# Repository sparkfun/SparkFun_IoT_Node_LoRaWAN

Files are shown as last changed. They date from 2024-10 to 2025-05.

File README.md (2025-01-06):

SparkFun IoT Node - LoRaWAN
========================================

SparkFun IoT Node - LoRaWAN (https://www.sparkfun.com/products/26060)

[*SparkFun IoT Node - LoRaWAN (WRL-26060)*](https://www.sparkfun.com/products/26060)




The SparkFun IoT Node – LoRaWAN development board brings an entirely new level of usability to the often convoluted and configuration-intensive effort to set up a LoRaWAN™-based IoT Device. Combining the ease of LoRaWAN™ setup and configuration delivered by the Digi X-ON™ system with the rapid prototyping provided by the SparkFun Qwiic ecosystem, the SparkFun IoT Node – LoRaWAN development board accelerates IoT end-node creation and deployment.  

**Out of the Box**

With the integration of Digi X-ON™ technology, the SparkFun IoT Node – LoRaWAN board allows the creation and deployment of a LoRaWAN™ IoT sensor in minutes. 

* Set up the Digi HX15 Gateway for LoRaWAN and corresponding Digi account.  
* Register the IoT Node – LoRaWAN board quickly using the digital data block on the module.
* Add the antenna and a supported Qwiic sensor to the Node board 
* Power the board  

The SparkFun IoT Node – LoRaWAN board is shipped with firmware installed that Digi HX15 Gateway for LoRaWAN automatically connects to Digi X-ON, detects an attached sensor, and posts data to the X-ON cloud. Configured via a serial console connection, this application allows rapid evaluation and creation of a LoRaWAN™ IoT device.  

The pre-installed application is also open source and readily available, enabling rapid customization if desired.

**Firmware Development**

The firmware development for the SparkFun IoT Node – LoRaWAN board is performed primarily in the Arduino environment and enabled by an Arduino XBee® LR library from Digi. Combining the easy LoRaWAN™ access provided by the Digi library with the wide range of Qwiic sensors available from SparkFun, the possibilities of potential LoRaWAN™ IoT sensors are endless. 

Additionally, the pre-installed application is open source and readily available, enabling rapid customization if desired.  

**Hardware**

At the heart of the IoT Node – LoRaWAN board is the RP2350 microprocessor from Raspberry Pi, supporting many development environments, including Arduino, micropython, and the Raspberry Pi pico SDK. Besides the capabilities the RP2350 provides, we’ve kitted out the processer with all the goodies your project might require: 

* 16 MB of flash 
* 8 MB PSRAM 
* Qwiic connector 
* On-board Lithium Ion (LiPo) battery charging 
* Fuel gauge circuits 
* microSD card  
* A variety of IO pins 
* RGB LED and user button 

The Digi XBee® LR module for LoRaWAN module is directly connected to a serial port of the RP2350, allowing direct control and access to the LoRaWAN™ module via a development library provided by Digi.  

The XBee® LR for LoRaWAN™ module is the latest LoRaWAN™ module from Digi, delivering unmatched operational performance and onboarding simplicity. The Digi XBee® LR uses LoRa™ modulation for Non-Line-of-Sight (NLOS) two-way communications for long-range and high-noise RF environments. Since each module is pre-activated on Digi's X-ON™ cloud platform, automated connection and two-way device management are a breeze.

Repository Contents
-------------------

* **/Hardware** - KiCAD design files (.brd, .sch)
* **/Documents** - Files related to the hardware on the board
* **/docs** - Hookup guide files

Documentation
--------------
* **[Hookup Guide](https://docs.sparkfun.com/SparkFun_IoT_Node_LoRaWAN)** - Basic hookup guide for the SparkFun IoT Node for LoRaWAN®.
* **[Firmware Guide](https://docs.sparkfun.com/sfe-iot-node-lorawan/)** - Firmware guide for the SparkFun IoT Node for LoRaWAN®.

License Information
-------------------

This product is _**open source**_! 

Please review the LICENSE.md file for license information. 

If you have any questions or concerns on licensing, please contact technical support on our [SparkFun forums](https://forum.sparkfun.com/viewforum.php?f=152).

Distributed as-is; no warranty is given.

- Your friends at SparkFun.

_<COLLABORATION CREDIT>_

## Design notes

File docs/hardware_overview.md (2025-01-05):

---
icon: material/cog
---

## XBee LR LoRaWAN® Module

The XBee® LR from Digi is a wireless communications module that supports the LoRaWAN® communications protocol, enabling direct communication with standards-compliant LoRaWAN® gateways and Network Server cloud software over long range with very low-power consumption. It comes pre-activated with Digi X-ON™ - a complete device-to-cloud platform for connected IoT devices which provides a simplified Digi Embedded API and AT command interpreter to interface with your sensor over serial. Scanning the QR Code on the module will take you directly to the Digi X-ON cloud platform for automated connection and two-way device management. For more information, refer to the [datasheet](assets/component_documentation/Digi-XBLR-Datasheet.pdf).

<!--ISM 902 to 928 MHz, 868 to 870 MHz
LoRaWAN® 1.0.4, OTAA, ABP
-->

<figure markdown>
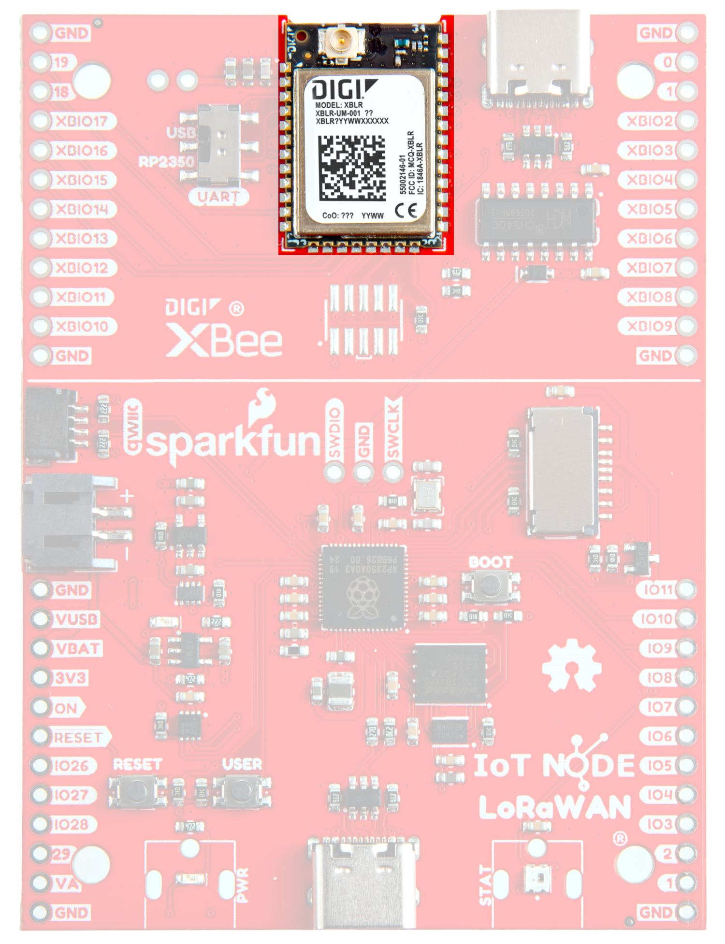
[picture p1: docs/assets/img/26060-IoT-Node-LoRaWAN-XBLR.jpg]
XBee LR LoRaWAN Module

<figcaption markdown>XBee LR LoRaWAN® Module</figcaption>
</figure>

## RP2350

The RP2350 is part of a new family of microcontrollers from Raspberry Pi that offers significant enhancements over RP2040. Along with the Dual ARM M33/RISC-V Hazard 3 CPU core running at a frequency of 150MHz and double the amount of internal RAM, the RP2350 also includes 8MB of PSRAM as well as a host of peripherals. As shipped, the SparkFun IoT Node for LoRaWAN® board makes use of the ARM M33 Core, but the user has the option to change to the RISC-V Hazard 3 CPU Core. More information can be found in the datasheet [here](assets/component_documentation/).

<figure markdown>
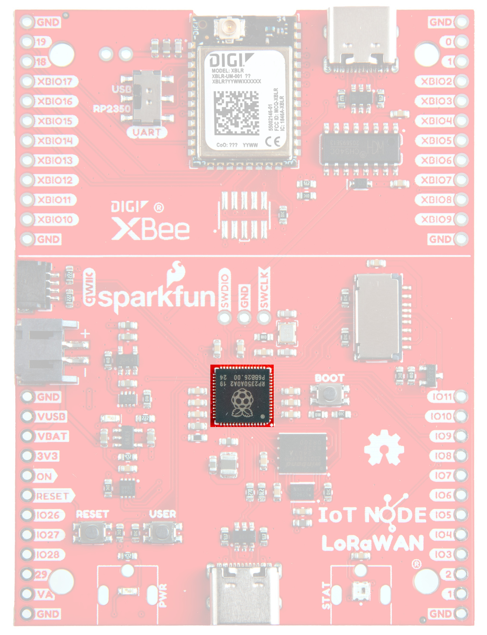
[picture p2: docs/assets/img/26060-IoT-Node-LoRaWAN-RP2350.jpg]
RP2350

<figcaption markdown>RP2350</figcaption>
</figure>

## Power & Voltage Regulation

While max input power is 5.5V for the board, the LM66200 regulates the voltage down to 3.3 for the majority of the components on the board. 

<figure markdown>
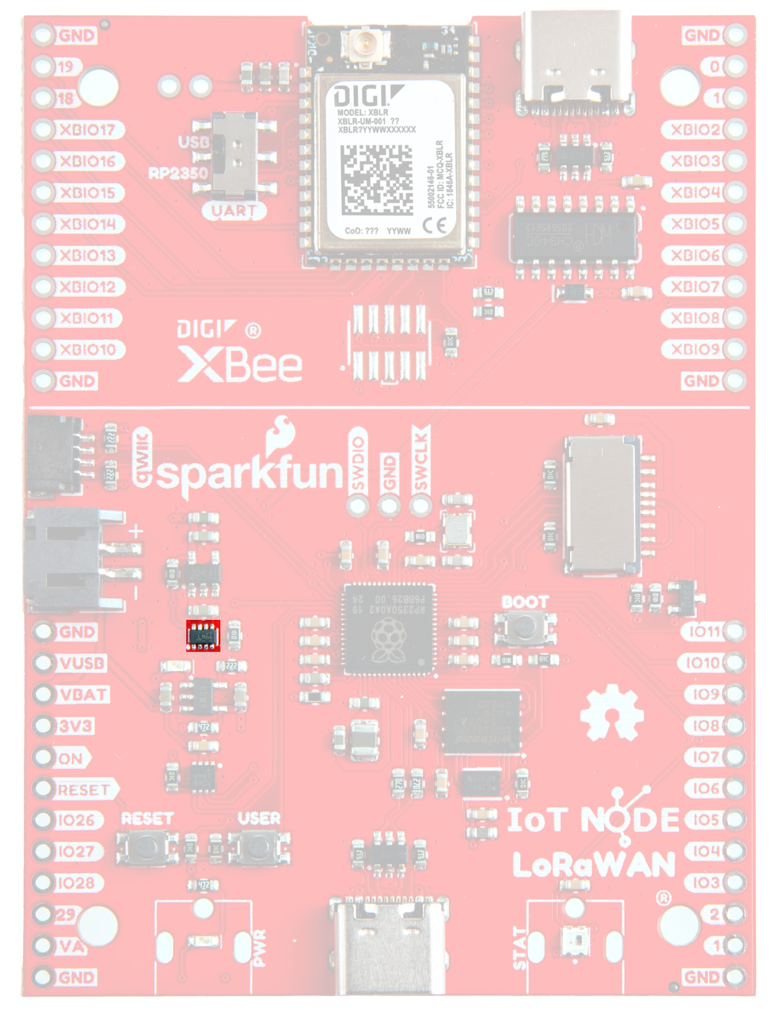
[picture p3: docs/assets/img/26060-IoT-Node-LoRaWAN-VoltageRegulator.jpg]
LM66200

<figcaption markdown>LM66200</figcaption>
</figure>

## Qwiic connector

The Qwiic connector on the side of the board provides power and I<sup>2</sup>C connectivity simultaneously to our rich array of Qwiic sensors. More information on our Qwiic Ecosystem [can be found here](https://www.sparkfun.com/qwiic). 

<figure markdown>
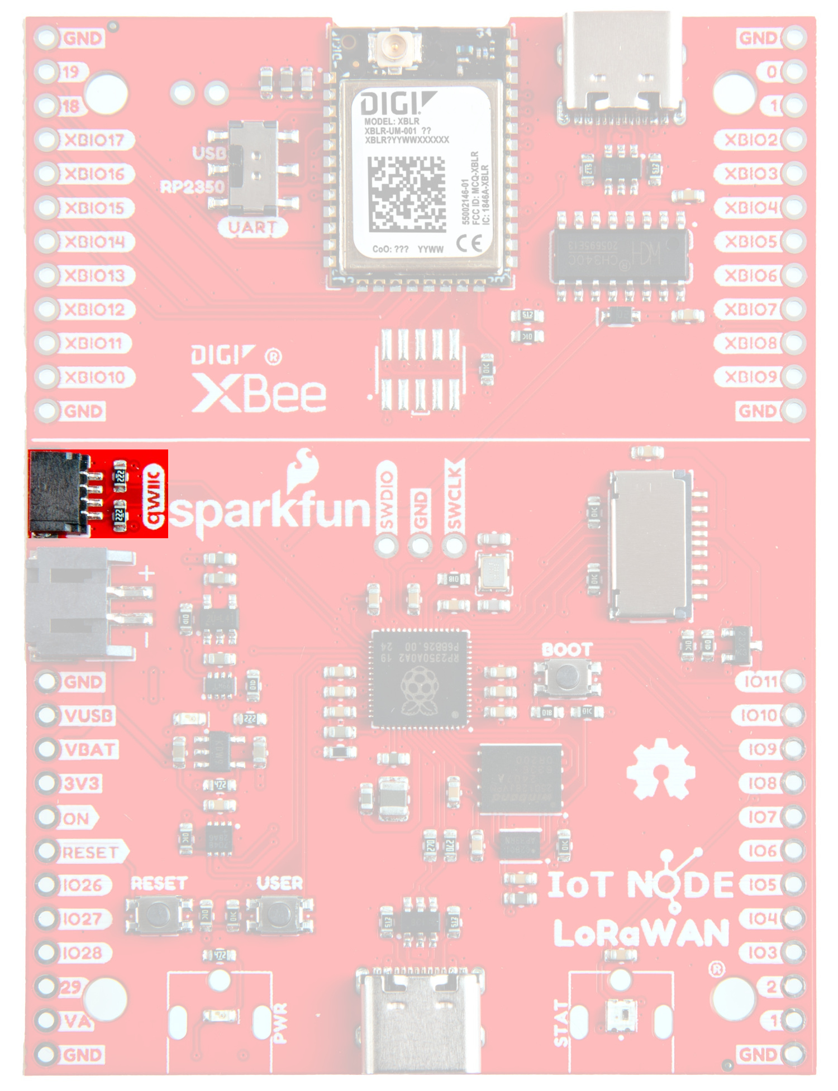
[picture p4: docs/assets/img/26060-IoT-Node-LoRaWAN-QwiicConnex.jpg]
Qwiic connector

<figcaption markdown>Qwiic connector</figcaption>
</figure>

## XBLR UART Selection Switch

This selection switch allows you to choose whether you talk to the XBee LR via the Raspberry Pi or the USB connector at the top of the board. Unless there is a need to talk to the XBee directly (ie, debugging, etc), it is recommended to leave the switch on the RP2350.

<figure markdown>
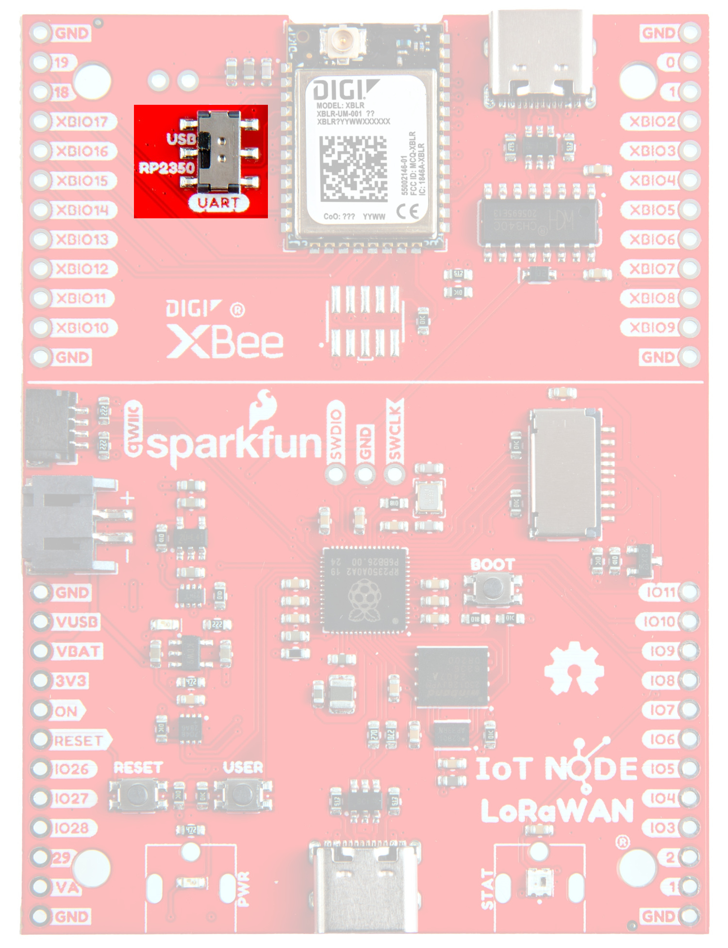
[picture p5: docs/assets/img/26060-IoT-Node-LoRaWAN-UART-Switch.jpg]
XBLR UART Selection Switch

<figcaption markdown>UART Selection Switch</figcaption>
</figure>

## RP2350 Debug Header

Should you need breakpoint level debugging, we've broken out a debug header for the RP2350. Standard pinout for the ARM Cortex. 

<figure markdown>
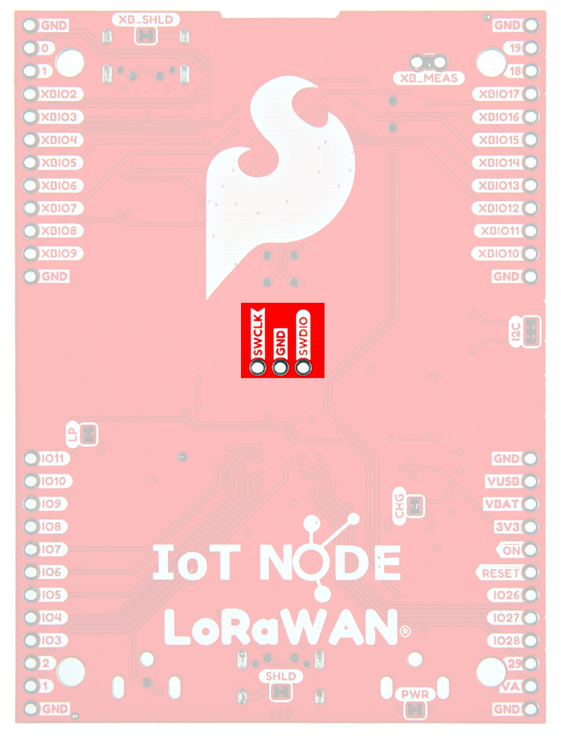
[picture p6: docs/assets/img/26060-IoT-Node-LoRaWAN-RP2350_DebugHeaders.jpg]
RP2350 Debug Headers

<figcaption markdown>RP2350 Debug Header</figcaption>
</figure>

## XBee LR Debug Header

Similar to the debug header for the RP2350, these pads allow for breakpoint level debugging of the XBee module. Unlike the RP2350 Debug Header, however, these pads are unpopulated. 

<figure markdown>
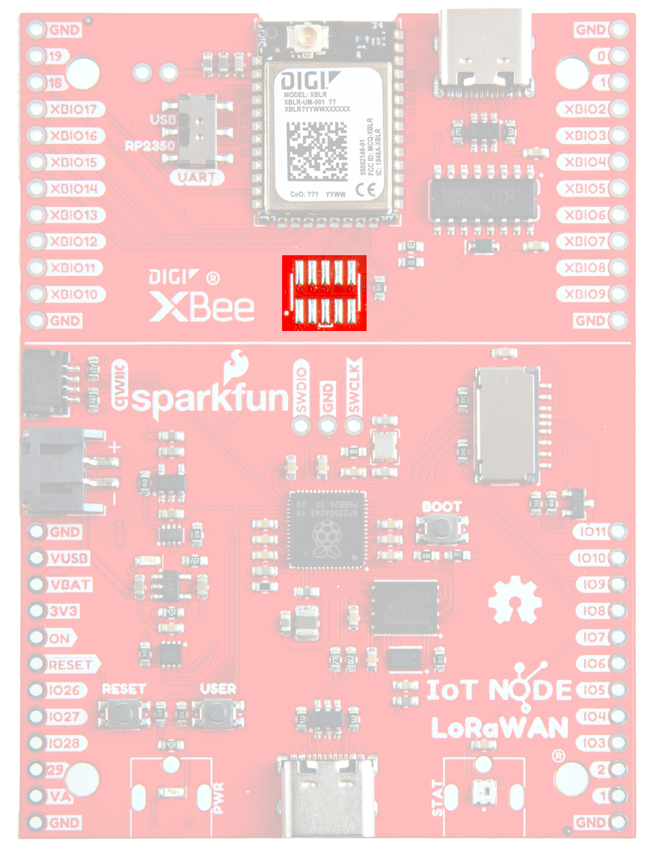
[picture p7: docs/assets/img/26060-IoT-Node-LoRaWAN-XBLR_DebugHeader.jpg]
XBee LR Debug Header

<figcaption markdown>XBee LR Debug Header</figcaption>
</figure>

## MicroSD Card

The microSD card slot allows for data logging or for more advanced users, easy upload of firmware programming files for the Raspberry Pi.

!!! warning
	Do NOT drive the microSD card pins high if the card is not powered. Damage could occur! 

<figure markdown>
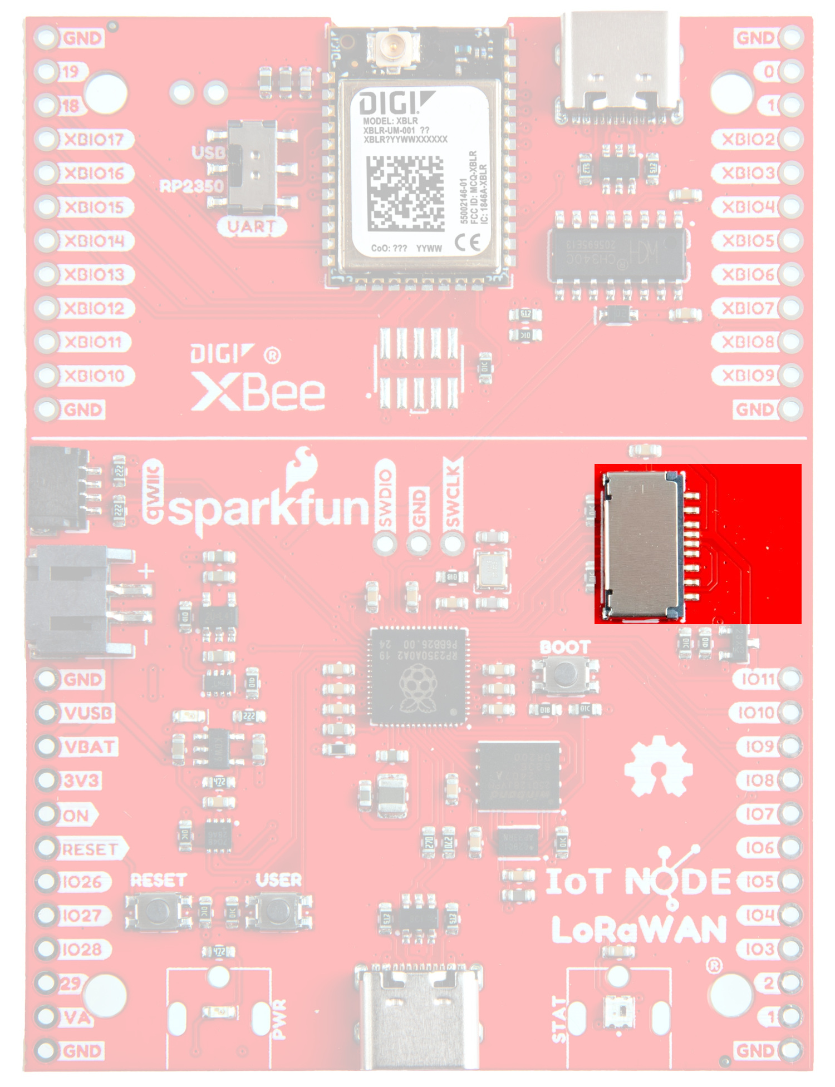
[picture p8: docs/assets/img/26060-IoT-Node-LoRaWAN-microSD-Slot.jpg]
microSD card slot

<figcaption markdown>microSD Card Slot</figcaption>
</figure>

## Battery Charging Circuit

The MCP73831 has been integrated to allow for charging of a LiPo Battery via the JST connector. 

<figure markdown>
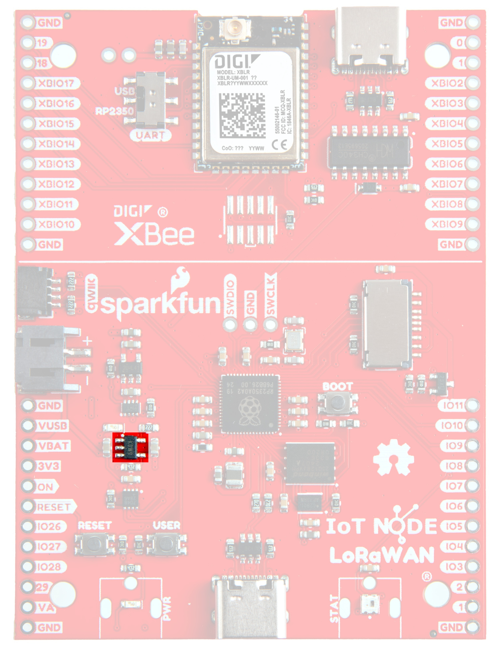
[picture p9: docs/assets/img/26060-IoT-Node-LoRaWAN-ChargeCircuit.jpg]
Battery Charging Circuit

<figcaption markdown>MCP73831</figcaption>
</figure>

Charging occurs at a rate of 455mA. Our calculation of this rate is via the equation below: 

<figure markdown>
Charge Circuit Equation
<figcaption markdown>Charge Circuit Equation</figcaption>
</figure>

## Buttons

<figure markdown>
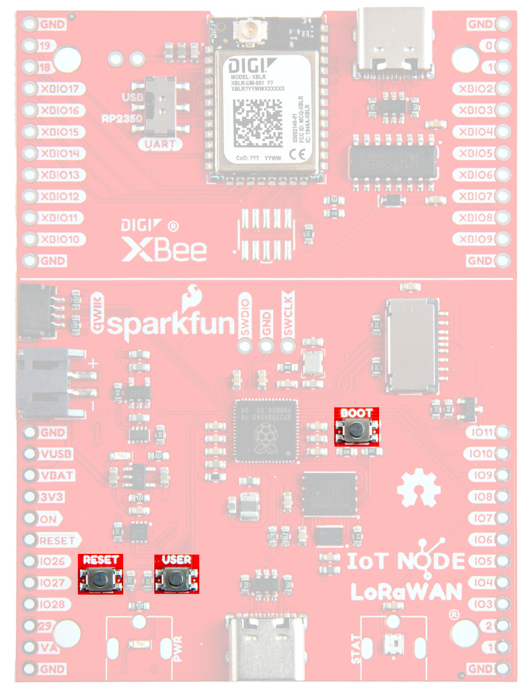
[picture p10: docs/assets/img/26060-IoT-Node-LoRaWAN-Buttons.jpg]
Boot, Reset, and User Buttons

<figcaption markdown>Boot, Reset, and User Buttons</figcaption>
</figure>

* <b>Boot:</b>
	Pressing and holding the boot button will set the board into boot select mode. This sets up as a mass storage device, which allows for drag-and-drop functionality for uploading uf2 programming files. For more information about the UF2 Bootloader, refer to the [Software/Bootloader](./uf2.md) section of this tutorial. 
* <b>Reset:</b>
	The reset button does a software reset on the RP2350. 
* <b>User Button:</b>
	The User Button is a user-defined general use button connected to GPIO. 

## Jumpers

??? note "Never modified a jumper before?"
	Check out our <a href="https://learn.sparkfun.com/tutorials/664">Jumper Pads and PCB Traces tutorial</a> for a quick introduction!
	<p align="center">
		<a href="https://learn.sparkfun.com/tutorials/664">
		Tutorial's thumbnail<br>
        How to Work with Jumper Pads and PCB Traces</a>
	</p>

<figure markdown>
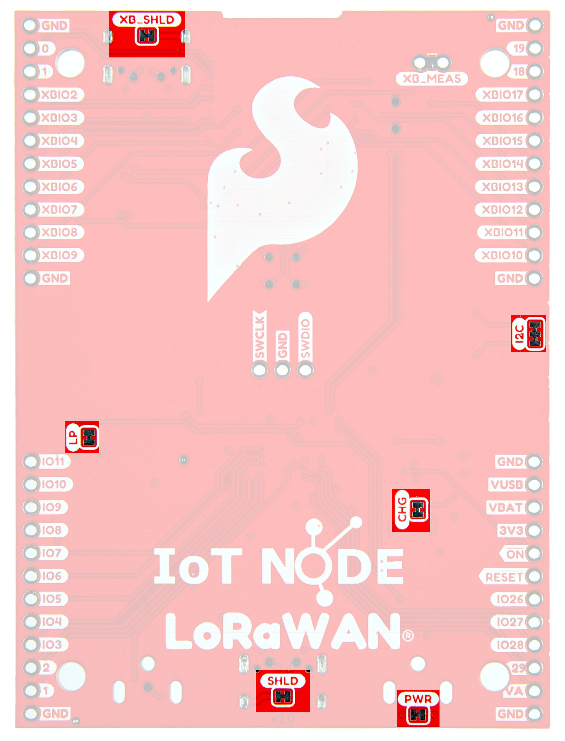
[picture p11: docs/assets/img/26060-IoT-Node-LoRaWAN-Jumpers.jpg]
Jumpers

<figcaption markdown>Jumpers</figcaption>
</figure>

* <b>XB_SHLD: </b>
	For most applications, single point grounding is sufficient. However, should you run into problems with EMI/EMC, we've provided a jumper that allow you to disconnect the XBee connector from ground.
* <b>XB_MEAS: </b>
	Cut this trace to measure the current consumed by the XBee LR. 
* <b>LP:</b>
	Cut the LP trace to make the microSD card and the RGB LED powered off by default. This functionality can then be controlled by GPIO. 
* <b>CHG:</b>
	Cut the CHG trace to disable the CHG LED. 
* <b>SHLD:</b>
	Should you run into problems with EMI/EMC, we've provided a jumper that allow you to disconnect the USB Shield from ground.
* <b>PWR:</b>
	Cut the PWR trace to disable the Power LED. 
* <b>I<sup>2</sup>C:</b>
	The SparkFun IoT Node for LoRaWAN® board has built-in 2.2k pull-up resistors on the SDA and SCL lines. These are needed for normal I<sup>2</sup>C communication. The I<sup>2</sup>C jumper has two small traces connecting the pull-ups to 3.3V. **For general use you can leave this jumper unmodified.** If you have many (over 7) devices on the I<sup>2</sup>C bus, each with their own pull up resistors, then you may want to [cut the I<sup>2</sup>C jumpers](https://learn.sparkfun.com/tutorials/how-to-work-with-jumper-pads-and-pcb-traces) to disconnect the 2.2k resistors on each Qwiic board.

## Board Dimensions

The board dimensions are illustrated in the drawing below; the listed measurements are in millimeters.

<figure markdown>
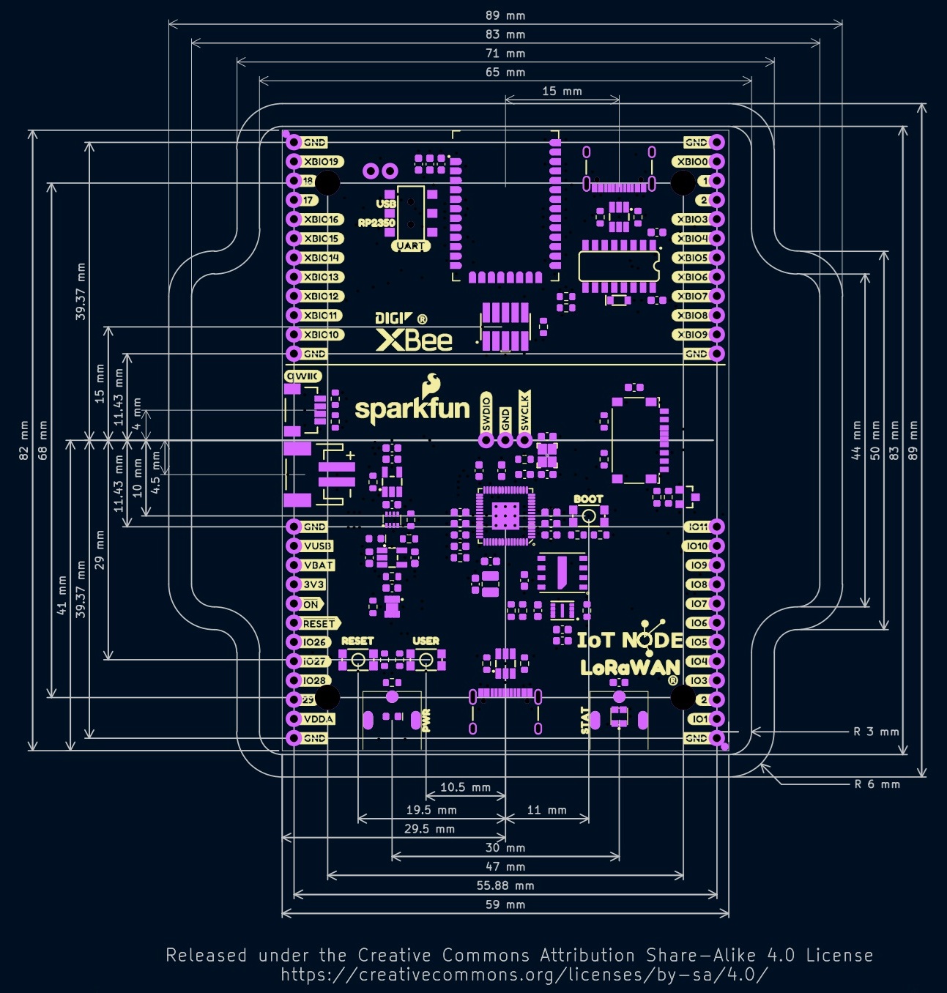
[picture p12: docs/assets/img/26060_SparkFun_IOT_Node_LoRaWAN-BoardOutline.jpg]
Board measures 59mm x 82mm

<figcaption markdown>SparkFun IoT Node for LoRaWAN® Board Dimensions</figcaption>
</figure>

??? tip "Need more measurements?"
	For more information about the board's dimensions, users can download the [KiCad files](../assets/board_files/SparkFun_IoT_Node_LoRaWAN_KiCADFiles.zip) for the board. These files can be opened in KiCad and additional measurements can be made with the dimensions tool.

	??? info ":octicons-download-16:{ .heart } Eagle - Free Download!"
		KiCAD is a [CAD]("computer-aided design") program for electronics that is free to use for hobbyists and students. However, it does require an account registration to utilize the software.

		<center>
		[Download from<br>:autodesk-primary:{ .autodesk }](https://www.kicad.org/download/ "Go to downloads page"){ .md-button .md-button--primary width="250px" }
		</center>

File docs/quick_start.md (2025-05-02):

---
icon: material/run-fast
hide: toc
---

<div class="grid cards desc" markdown>

-    <a href="https://www.sparkfun.com/products/26060">
    **SparkFun IoT Node for LoRaWAN®**<br>
    **SKU:** WRL-26060

    ---

    <figure markdown>
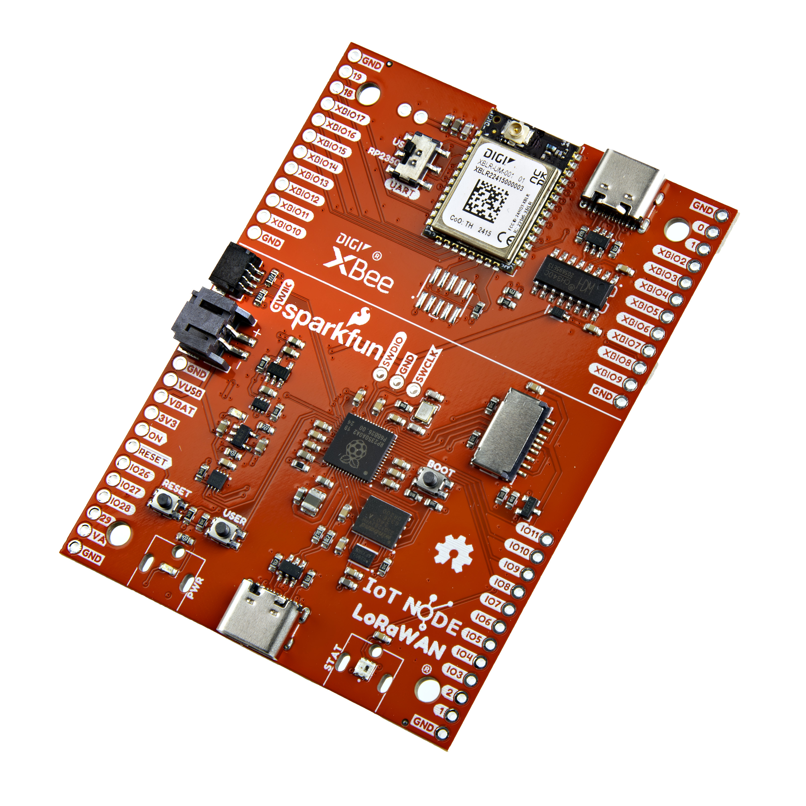
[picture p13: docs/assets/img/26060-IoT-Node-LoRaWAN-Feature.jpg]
Product Thumbnail
    
    </figure></a>
    
-    The SparkFun IoT Node for LoRaWAN® development board brings an entirely new level of usability to the often convoluted and configuration-intensive effort to set up a LoRaWAN®-based IoT Device. Combining the ease of LoRaWAN® setup and configuration delivered by the Digi X-ON™ system with the rapid prototyping provided by the SparkFun Qwiic ecosystem, the SparkFun IoT Node for LoRaWAN® development board accelerates IoT end-node creation and deployment.

    <center>
    [Purchase from SparkFun :fontawesome-solid-cart-plus:{ .heart }](https://www.sparkfun.com/products/26060){ .md-button .md-button--primary }
    </center>

</div>

## Getting Started with Digi

To get started, you'll need to have access to an HX15 Gateway (NA or EU version) and a Digi Account. If you've purchased the kit, a Gateway will be included. Digi has a great ["Getting Started" video here](https://youtu.be/nrmTp8ZYa6c?si=9FnklldcUvFMTXLr). The kit also has a welcome card included that contains a QR Code. Scanning this code will take you to a URL where you can register for an account.

<!--If you've already registered with Digi, go ahead to this link to log in: 

<center>
[Digi Login :fontawesome-solid-user:{ .heart }](https://us1.haxiot.com/){ .md-button .md-button--primary }
</center>

--There are a number of things required to get started, all of which are available in the LoRaWAN kit:

NA version: https://sparkle.sparkfun.com/sparkle/storefront_products/27213#tab-dashboard
EU version: https://sparkle.sparkfun.com/sparkle/storefront_products/27214#tab-dashboard. 

The kit comes with the HX15 Gateway (NA or EU version), IoT Node, antennas, cables, a Qwiic sensor, welcome cards, etc. You'll only need 1 gateway, so once the kit is purchased, expansion only requires the components necessary for additional nodes (SparkFun IoT LoRaWAN Node, antenna, sensors, batteries, etc.).

If you've purchased the kit, there will be a welcome card included that contains a QR Code. Scanning this code will take you to a URL where you can register for an account. 
-->

## Register the LoRaWAN® Node

To provision a device, go to the following [link](https://scan-us1.haxiot.com/), log in if necessary, and scan the Data Matrix on the XBee. We recommend using the camera on a mobile device/phone to scan the Data Matrix.

<figure markdown>
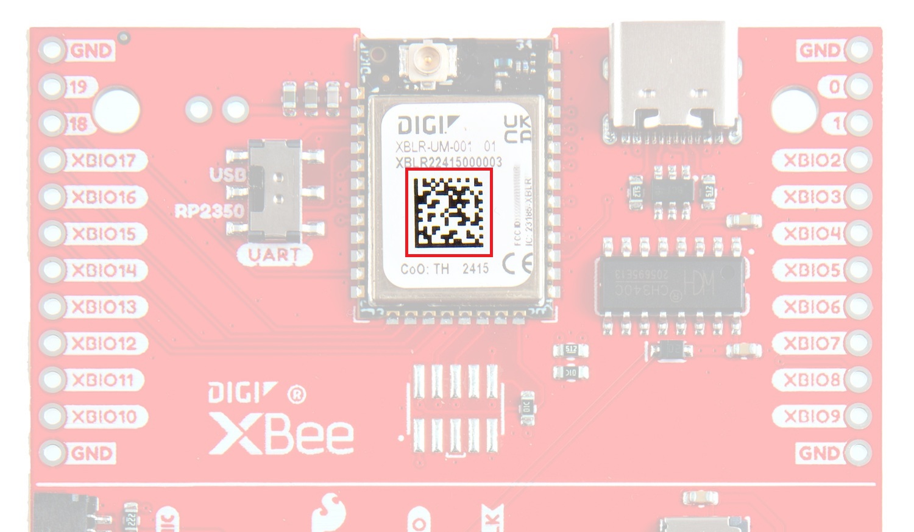
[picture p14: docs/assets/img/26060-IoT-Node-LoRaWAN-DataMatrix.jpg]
Data Matrix on the XBee

<figcaption markdown>Data Matrix on the XBee</figcaption>
</figure>

!!! note
    If your DataMatrix scan is too blurry to work, wait a few moments and a manual entry will appear. From here you can manually enter the serial number to register your device. Alternatively, the mobile version has a zoom slider.  

    <figure markdown>
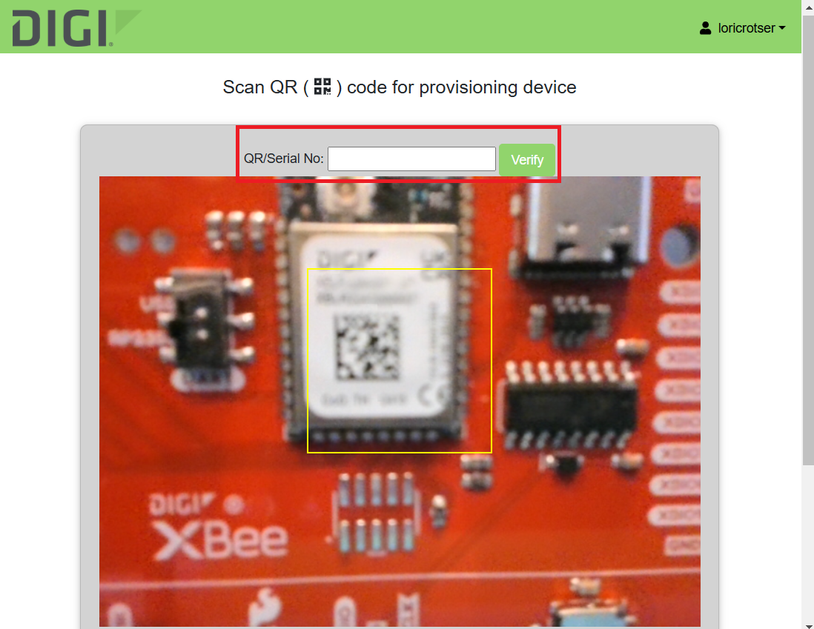
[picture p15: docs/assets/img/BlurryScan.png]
Manual Entry for XBee Module
    
    <figcaption markdown>Manual Entry for XBee Module</figcaption>
    </figure>

## Digi Devices

Once you've registered your SparkFun IoT Node for LoRaWAN® board, you'll see it in your devices. Go to **Network Dashboard** -> **Devices**

<figure markdown>
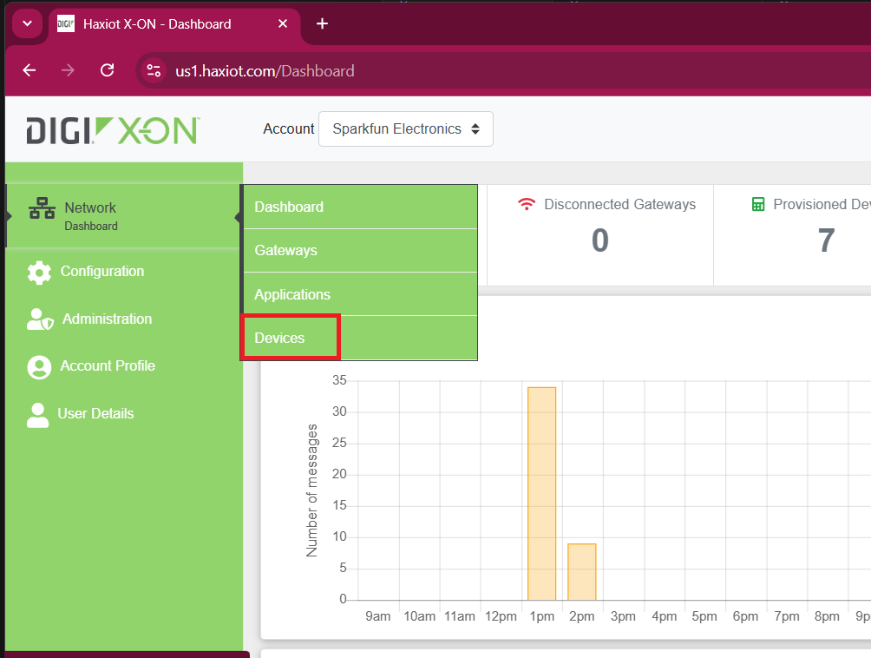
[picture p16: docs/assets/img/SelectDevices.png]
Devices on Digi

<figcaption markdown>Devices on Digi</figcaption>
</figure>

Make sure you've got the correct Application selected like so: 

<figure markdown>
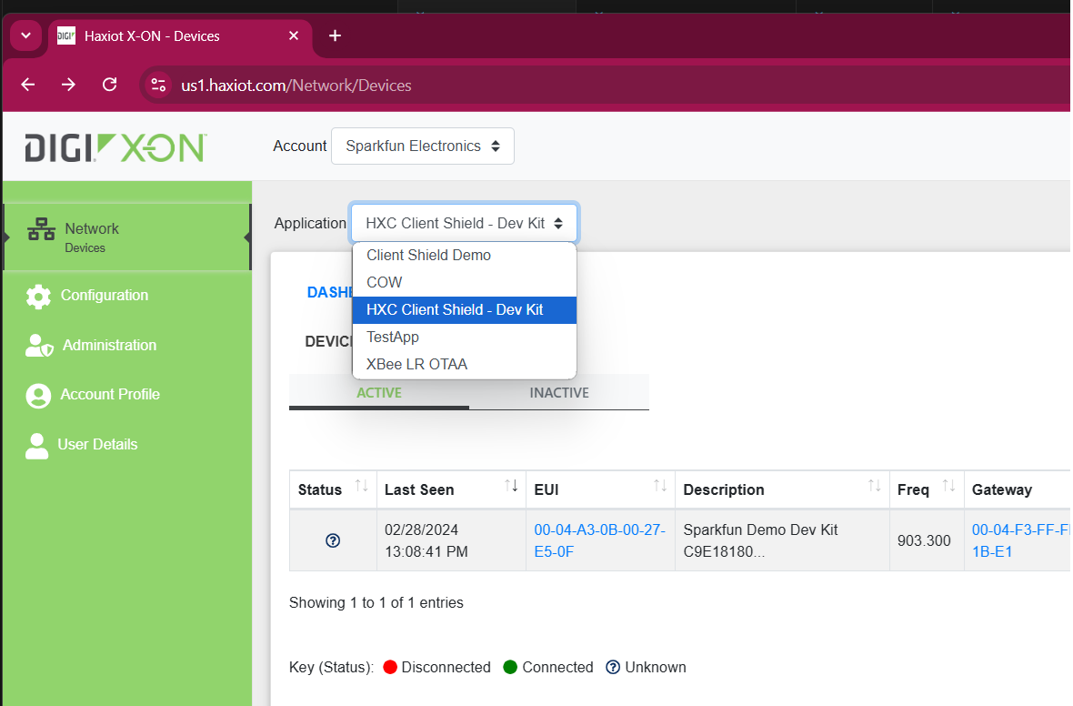
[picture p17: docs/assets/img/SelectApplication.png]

<figcaption markdown>Application on Digi</figcaption>
</figure>

You'll see your device here. 

<figure markdown>
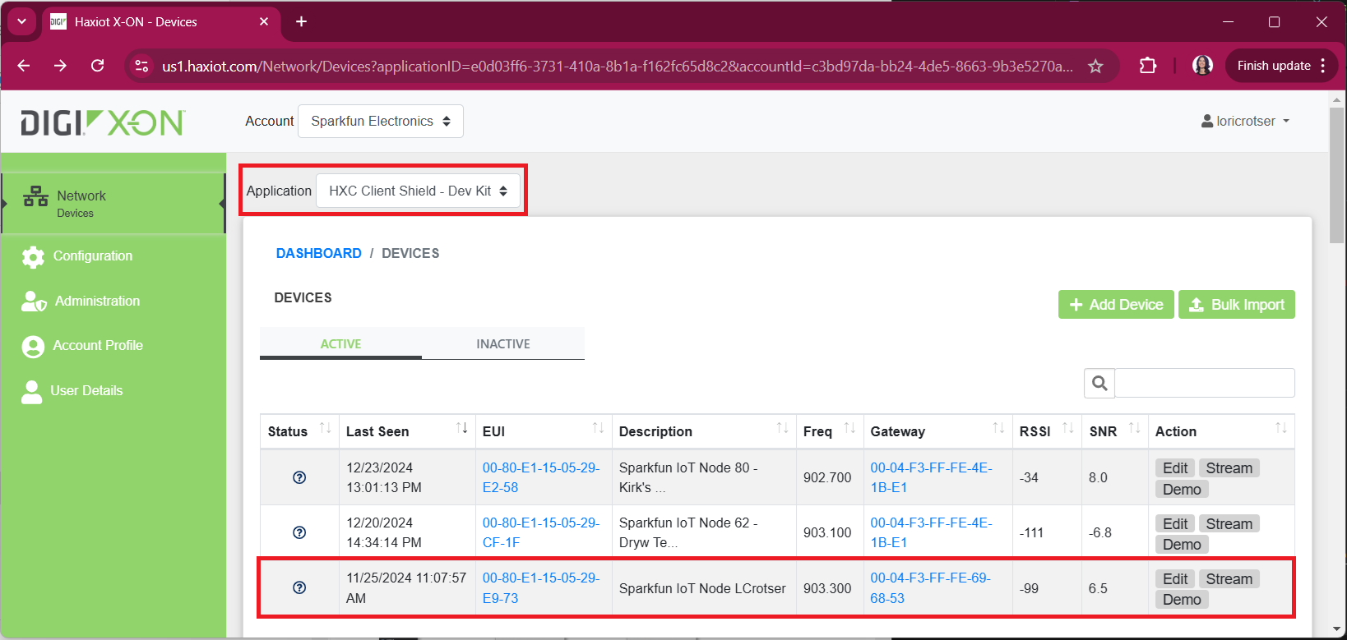
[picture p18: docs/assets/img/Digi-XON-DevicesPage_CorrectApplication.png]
Devices on Digi

<figcaption markdown>Devices on Digi</figcaption>
</figure>

## Plug in a Qwiic Sensor

Our [Qwiic Ecosystem](https://www.sparkfun.com/qwiic) has an array of plug and play sensors. For the pre-programmed firmware, you'll need the [SparkFun Environmental Combo Breakout - ENS160/BME280 (Qwiic)](https://www.sparkfun.com/products/22858); plug it into the Qwiic port as shown here: 

<figure markdown>
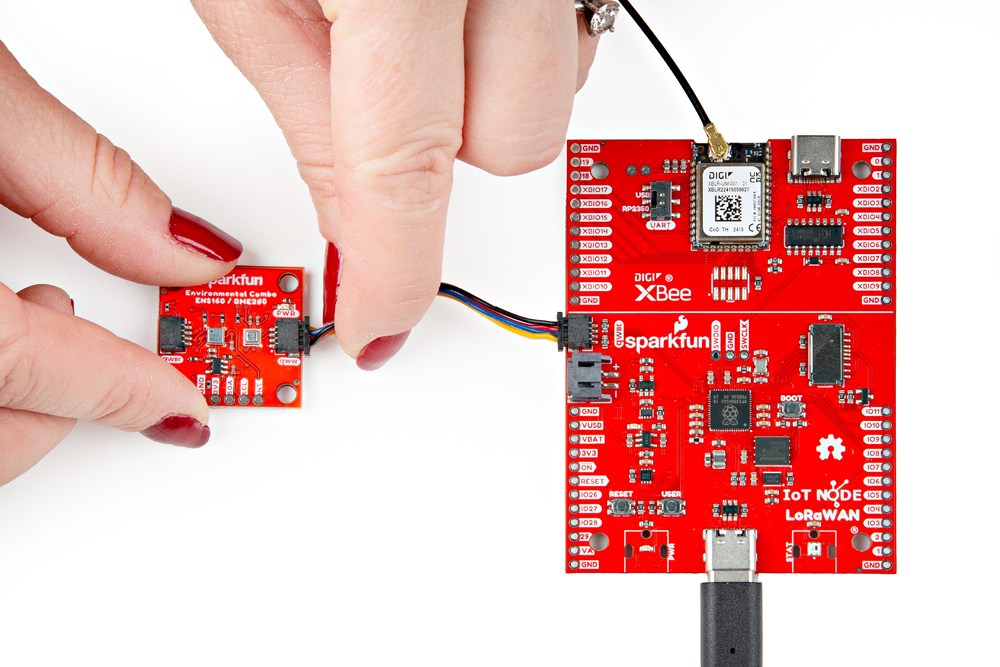
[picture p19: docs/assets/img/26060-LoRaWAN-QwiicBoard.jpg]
LoRaWAN connected to Qwiic board

<figcaption markdown>Connecting a Qwiic Sensor to the SparkFun IoT Node for LoRaWAN® Board</figcaption>
</figure>

## Reading Firmware

The SparkFun IoT Node for LoRaWAN® comes with Firmware that allows for a number of settings. By default, you can leave this be, but if you're interested in changing settings or verifying that everything is working you can pull up your favorite terminal (Putty, TeraTerm, etc), connect via serial to the port your LoRaWAN® has enumerated on, and you should see something like the following: 

<figure markdown>
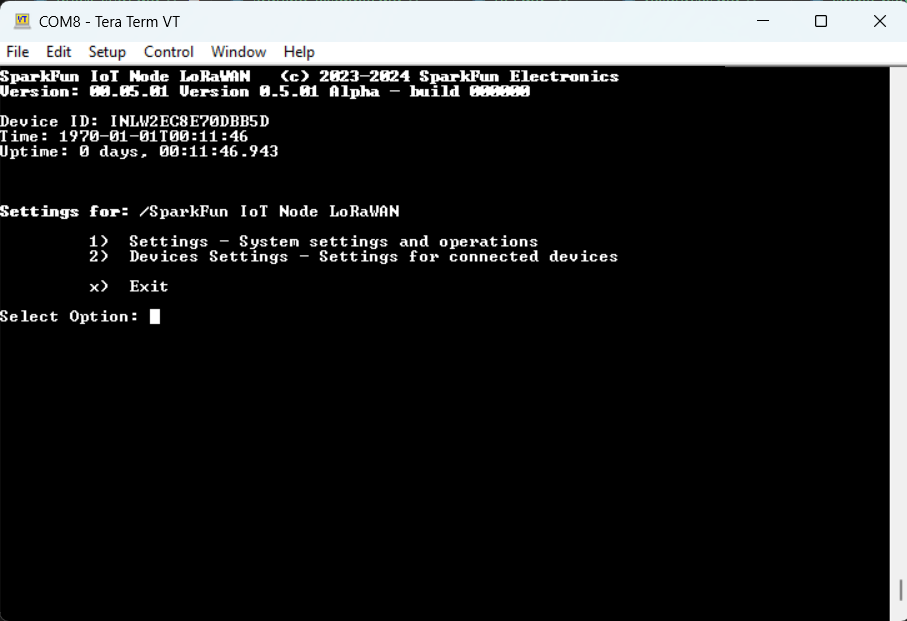
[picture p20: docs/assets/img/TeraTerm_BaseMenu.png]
Connecting with TeraTerm

<figcaption markdown>Connecting with TeraTerm</figcaption>
</figure>

There are a number of different menus and settings you can scroll through at your leisure. Head over to the [Firmware Tutorial](https://docs.sparkfun.com/sfe-iot-node-lorawan) for more information. 

## Reading Data

If nothing is entered in the above window, the LoRaWAN® will use default settings and start running. 

<figure markdown>
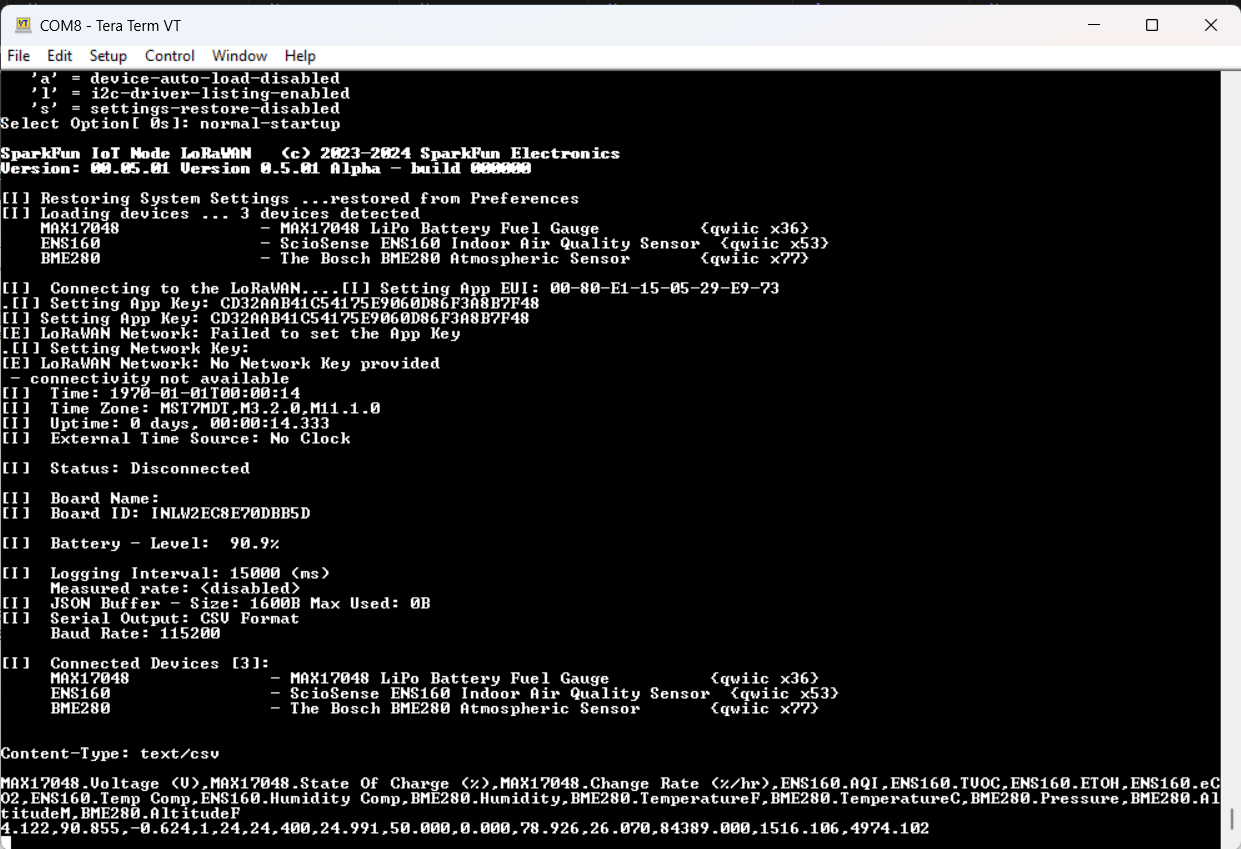
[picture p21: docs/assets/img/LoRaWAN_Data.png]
Reading Data

<figcaption markdown>Reading Data</figcaption>
</figure>

This data will upload to your Digi Account via your gateway and can be seen here under Dashboard / Devices / Device Details: 

<figure markdown>
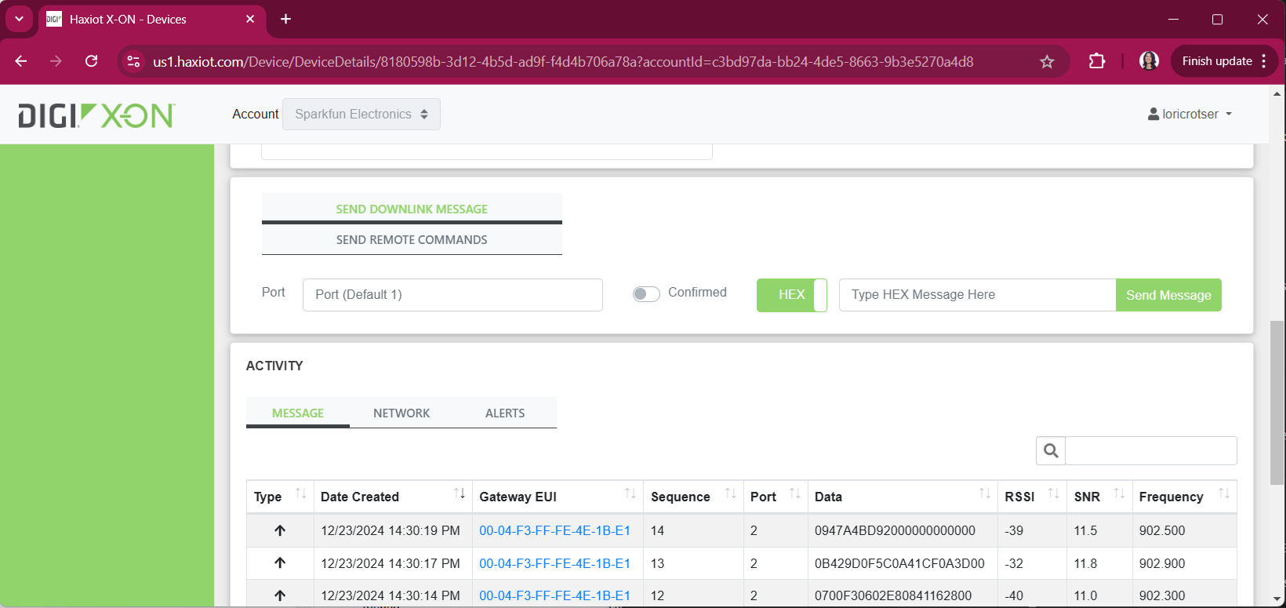
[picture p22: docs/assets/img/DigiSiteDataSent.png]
Data Packets

<figcaption markdown>Data Packets</figcaption>
</figure>

## Device Details and Management

Clicking on your device's EUI will take you to a page with Device Details, including the packets sent and gateway strength. 

<figure markdown>
Device Details Page
<figcaption markdown>Device Details Page</figcaption>
</figure>

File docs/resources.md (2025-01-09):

<!-- This section should include all the relevant documentation and product files (Eagle files, schematic, datasheet(s), landing pages, etc. and any relevant tutorials to go beyond the Hookup Guide.) -->

For more resources related to the SparkFun IoT Node for LoRaWAN®, check out the links listed here: 

* [Product Page](https://www.sparkfun.com/products/26060)
* [Schematic](https://docs.sparkfun.com/SparkFun_IoT_Node_LoRaWAN/assets/board_files/26060_SparkFun_IoT_Node_LoRaWAN_Schematic.pdf)
* [KiCad Files](https://docs.sparkfun.com/SparkFun_IoT_Node_LoRaWAN/assets/board_files/SparkFun_IoT_Node_LoRaWAN_KiCADFiles.zip)
* [Board Dimensions](https://docs.sparkfun.com/SparkFun_IoT_Node_LoRaWAN/assets/img/26060_SparkFun_IOT_Node_LoRaWAN-BoardOutline.jpg)
* [Graphical Datasheet](https://docs.sparkfun.com/SparkFun_IoT_Node_LoRaWAN/assets/board_files/26060_SparkFun_IoT_Node_LoRaWAN_GDS.pdf)
* [GitHub Hardware Repository](https://github.com/sparkfun/SparkFun_IoT_Node_LoRaWAN)
* Datasheets
    * [RP2350](https://cdn.sparkfun.com/assets/0/7/7/c/4/rp2350-datasheet.pdf)
    * [Digi XBee LR Datasheet](https://cdn.sparkfun.com/assets/c/7/e/8/d/Digi-XBLR-Datasheet.pdf)
    * [Digi HX15 Gateway Datasheet](https://cdn.sparkfun.com/assets/c/8/f/f/7/Digi-HX15-Datasheet.pdf)
* [Digi XBee LR User Manual](https://cdn.sparkfun.com/assets/6/2/4/f/a/90002591.pdf)
* [Digi XBee LR Hardware Manual](https://cdn.sparkfun.com/assets/9/c/c/9/9/90002592.pdf)
* [RP2350 Product Brief](https://datasheets.raspberrypi.com/rp2350/rp2350-product-brief.pdf)
* [Raspberry Pi RP2350 Microcontroller Documentation](https://www.raspberrypi.com/documentation/microcontrollers/silicon.html#rp2350)
* [Qwiic Info Page](https://www.sparkfun.com/qwiic)

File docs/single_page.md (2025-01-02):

---
hide:
  - navigation
  - toc
icon: fontawesome/solid/scroll
---

--8<-- "./docs/quick_start.md:5"

# Hardware Overview
--8<-- "./docs/hardware_overview.md:5"

# Hardware Assembly
--8<-- "./docs/hardware_assembly.md:5"

# Hardware Assembly
--8<-- "./docs/prepare_your_microsd_card.md:5"

# Hardware Assembly
--8<-- "./docs/uf2.md:5"

# Troubleshooting Tips
--8<-- "./docs/troubleshooting.md:5"

# Resources:
--8<-- "./docs/resources.md"

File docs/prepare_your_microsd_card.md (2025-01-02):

Not all microSD cards are created equal. The [capacity, read/write speed, and format](https://learn.sparkfun.com/tutorials/sd-cards-and-writing-images) vary depending on the manufacturer. In order to log data to the microSD card, you will need to ensure that your memory card is formatted as **FAT32**. You can also use FAT16. If the memory card is formatted as a different memory card, the DataLogger IoT will not be able to recognize the microSD card.

## Checking MicroSD Card Format

While you can simply insert the microSD card into your SparkFun IoT Node for LoRaWAN® and start logging, there may be a chance that the it will not recognize the memory card due to the format.

### Checking MicroSD Card Format - Windows

To check to see if it is the correct format on a Windows you could head to the drive, right click, and select **Properties**.

<figure markdown>
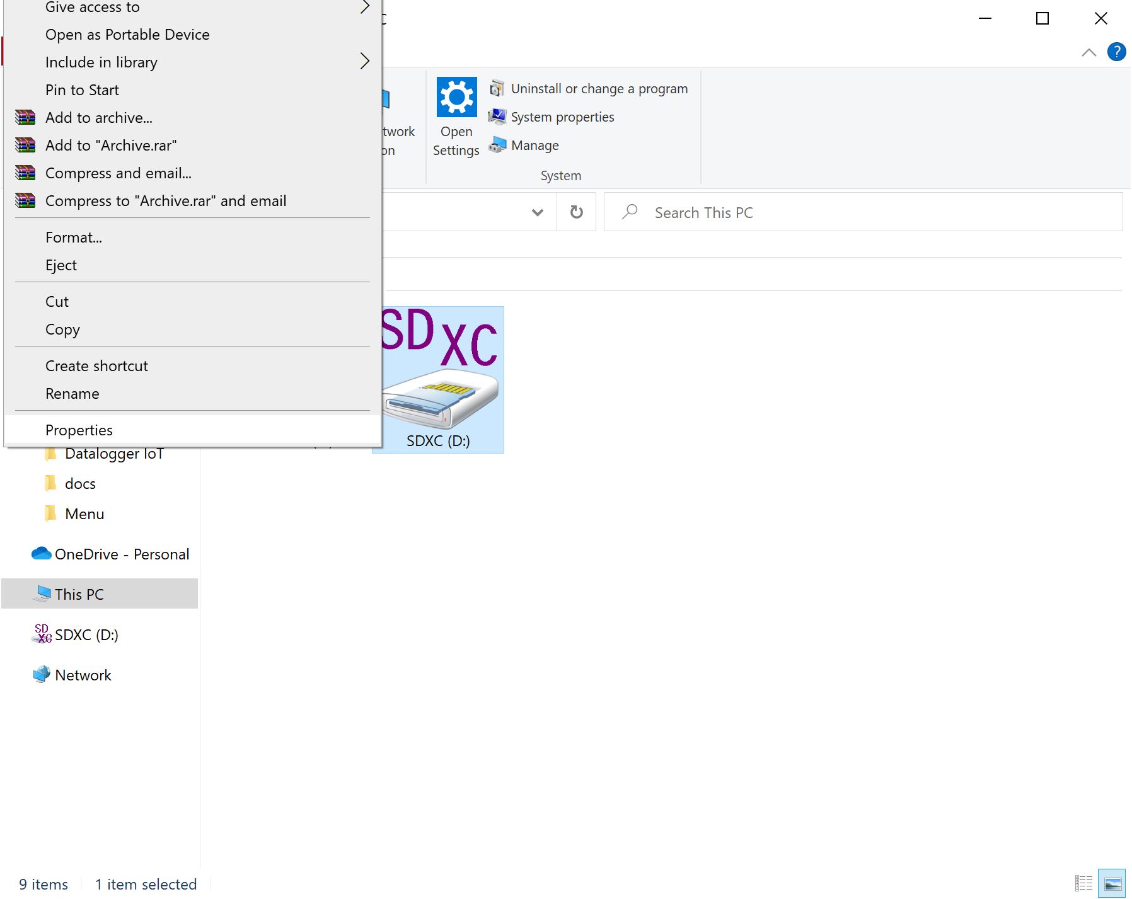
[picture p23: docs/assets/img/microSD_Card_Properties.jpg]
microSD Card Properties

<figcaption markdown>microSD Card Properties</figcaption>
</figure>

Once the properties are open, you should be able to tell what file system that the memory card uses. In this case, it was exFAT which is not compatible with the DataLogger IoT. You will need to reformat the memory card since it is not formatted as FAT32.

<figure markdown>
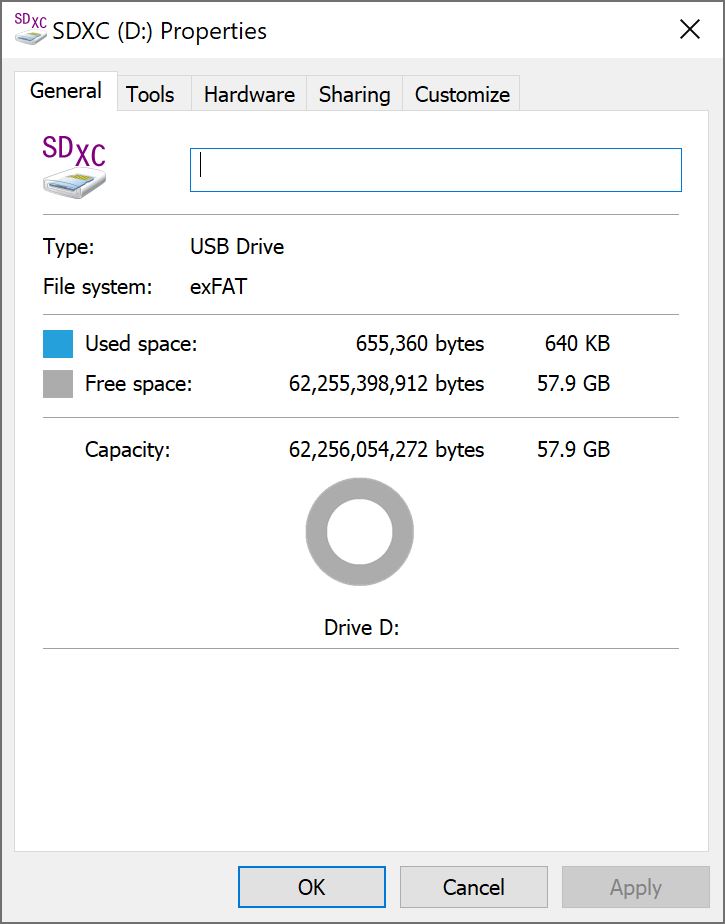
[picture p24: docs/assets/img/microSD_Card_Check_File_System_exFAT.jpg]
Check File System Windows

<figcaption markdown>Check File System Windows</figcaption>
</figure>

### Checking MicroSD Card Format - macOS

To check to see if it is the correct format on a macOS, you could head to the drive on your desktop. Then right click, and select **Get Info**.

<figure markdown>
Get Info on MicroSD Card
<figcaption markdown>Get Info on MicroSD Card</figcaption>
</figure>

A window will pop up indicating the microSD card properties. Under **General:** > **Format:**, you should be able to tell what file system that the memory card uses. In this case, it was exFAT which is not compatible with the DataLogger IoT. You will need to reformat the memory card since it is not formatted as FAT32.

<figure markdown>
exFAT
<figcaption markdown>exFAT</figcaption>
</figure>

## Download Raspberry Pi Imager

There are a few methods and programs available to reformat your microSD card as a FAT32. We found it easier to use the [Raspberry Pi Imager Tool](https://www.raspberrypi.com/software/). Of course, you will only be using the tool to erase the contents of the microSD card and formatting it as a FAT32 system. You will not actually flash any image to the memory card. Click on the button below to download the tool from the Raspberry Pi Foundation. It is supported on *Windows*, *macOS*, and *Ubuntu for x86*.

<div style="text-align: center"><a href="https://www.raspberrypi.com/software/" target="rpi_imager_tool" class="md-button">Raspberry Pi Imager Tool</a></div>

## Formatting as FAT32 using the Raspberry Pi Imager

After downloading and installing the software, open the Raspberry Pi Imager.

<figure markdown>
Raspberry Pi Imager
<figcaption markdown>Raspberry Pi Imager</figcaption>
</figure>

Under "**Operating System**", select "**Erase**" to "format card as FAT32."

<figure markdown>
Raspberry Pi Imager - Erase : Format as FAT32
<figcaption markdown>Raspberry Pi Imager - Erase : Format as FAT32</figcaption>
</figure>

Under "**Storage**", select the drive that the microSD card appeared as on your computer.

<figure markdown>
Raspberry Pi Imager - Select Storage Drive
<figcaption markdown>Raspberry Pi Imager - Select Storage Drive</figcaption>
</figure>

When ready, select "**Write**". After a few minutes, the microSD card should be formatted with FAT32.

<figure markdown>
Raspberry Pi Imager - Write
<figcaption markdown>Raspberry Pi Imager - Write</figcaption>
</figure>

Once the memory card has finished formatting, eject the microSD from your computer. To check to see if the microSD card is formatted as FAT32, you can check its properties as explained earlier with your operating system. Below shows a screenshot from a Windows and macOS showing that the microSD card reformatted as a FAT32 file system.

<figure markdown>
Check File System Windows
<figcaption markdown>Check File System Windows</figcaption>
</figure>

<figure markdown>
Check File System macOS
<figcaption markdown>Check File System macOS</figcaption>
</figure>

<!--
<table class="table table-hover table-striped table-bordered">
  <tr style="vertical-align:middle;">
   <td style="text-align: center; vertical-align: middle;"><a href="https://github.com/sparkfun/SparkFun_DataLogger/blob/main/docs/assets/img/microSD_Card_Check_File_System_FAT32.jpg"><img src="https://github.com/sparkfun/SparkFun_DataLogger/blob/main/docs/assets/img/microSD_Card_Check_File_System_FAT32.jpg" alt="Check File System Windows"></a></td>
   <td style="text-align: center; vertical-align: middle;"><a href="https://github.com/sparkfun/SparkFun_DataLogger/blob/main/docs/assets/img/mac_microSD_FAT32.png"><img src="https://github.com/sparkfun/SparkFun_DataLogger/blob/main/docs/assets/img/mac_microSD_FAT32.png" alt="Check File System macOS"></a></td>
  </tr>
  <tr style="vertical-align:middle;">
  <td style="text-align: center; vertical-align: middle;"><i>Check File System Windows</i></td>
  <td style="text-align: center; vertical-align: middle;"><i>Check File System macOS</i></td>
  </tr>
</table>
-->

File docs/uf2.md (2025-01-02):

The SparkFun IoT Node for LoRaWAN® uses a UF2 bootloader for easy flashing/uploading of code to the board. The UF2 bootloader causes the board to show up on your computer as a USB storage device and does <b>not</b> require any drivers for Windows, Mac OSX, and Linux. This bootloader is used for uploading in both the Pico SDK and MicroPython development environments so let's take a brief look at how to enter bootload mode.

## What is UF2?

UF2 stands for USB Flashing Format, which was developed by Microsoft for PXT (now known as MakeCode) for flashing microcontrollers over the Mass Storage Class (MSC), just like a removable flash drive. The file format is unique, so unfortunately, you cannot simply drag and drop a compiled binary or hex file onto the board. Instead, the format of the file has extra information to tell the processor where the data goes, in addition to the data itself. For more information about UF2, you can read more from the [MakeCode blog](https://makecode.com/blog/one-chip-to-flash-them-all), as well as the [UF2 file format specification](https://github.com/Microsoft/uf2).

## Entering the Bootloader

Putting the SparkFun IoT Node for LoRaWAN® into bootloader mode only requires a couple of presses of the BOOT and RESET buttons. Start by pressing and holding the BOOT button down:

<figure markdown>
Pressing the BOOT button
</figure>

Next, press and release the RESET button while still holding down the BOOT button:

<figure markdown>
Photo highlighting IoT Node LoRaWAN.
</figure>

Release the RESET button and then the BOOT button and the board should be in bootloader mode and appear on your computer as a USB storage device called "RP2350".

<figure markdown>
Photo highlighting IoT Node LoRaWAN.
</figure>

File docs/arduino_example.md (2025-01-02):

---
icon: simple/arduino
---

https://scan-us1.haxiot.com/?returnUrl=%2FScan%2FProvision%2F

https://scan-us1.haxiot.com/

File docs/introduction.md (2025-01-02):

---
icon: material/book-open-page-variant
---

<div class="grid cards desc" markdown>

-    <a href="https://www.sparkfun.com/products/26060">
    **SparkFun IoT Node - LoRaWAN**<br>
    **SKU:** WRL-26060

    ---

    <figure markdown>
    ![Product Thumbnail]()
    </figure></a>
    
-    The SparkFun IoT Node - LoRaWAN is a dual-action board that combines the exceptional LoRaWAN capabilities of the Digi XBee LR module with the RP2350 - a new family of microcontrollers from Raspberry Pi that offers significant enhancements over the RP2040 line. With Digi's Scan and Go Provisioning App, you'll have a data-ready device solution from development to operation up and running in no time.

    Digi XBee LR modules are pre-activated on the Digi X-ON cloud platform for automated connection and two-way device management. The Digi XBee LR module provides a simplified Digi Embedded API and AT command interpreter to interface with your sensor over serial.

<center>
[Purchase from SparkFun :fontawesome-solid-cart-plus:{ .heart }](https://www.sparkfun.com/products/26060){ .md-button .md-button--primary }
</center>

</div>

## Required Materials

To follow along with this tutorial, you will need the following materials. You may not need everything, depending on what you have. Add it to your cart, read through the guide, and adjust the cart as necessary.

<table style="border-style:none">
    <tr>
        <td>
            <a href="https://www.sparkfun.com/products/26060">
                
                <h3 class="title">SparkFun IoT Node - LoRaWAN</h3>
            </a>
            WRL-26060
        </td>
    </tr>
</table>

## Suggested Reading

Below are a few tutorials that may help users familiarize themselves with various aspects of the board.

<div class="grid cards hide col-4" markdown align="center">

-   <a href="https://learn.sparkfun.com/tutorials/how-to-solder-through-hole-soldering">
    <figure markdown>
    How to Solder: Through-Hole Soldering
    </figure>
    </a>
    <a href="https://learn.sparkfun.com/tutorials/how-to-solder-through-hole-soldering">**How to Solder: Through-Hole Soldering**
    </a>

-   <a href="https://learn.sparkfun.com/tutorials/sending-sensor-data-over-lora">
    <figure markdown>
    Sending Sensor Data over LoRa
    </figure>
    </a>
    <a href="https://learn.sparkfun.com/tutorials/sending-sensor-data-over-lora">**Sending Sensor Data over LoRa**
    </a>

-   <a href="https://learn.sparkfun.com/tutorials/534">
    <figure markdown>
    Connectivity of the Internet of Things
    </figure>
    </a>
    <a href="https://learn.sparkfun.com/tutorials/534">**Connectivity of the Internet of Things**
    </a>

-   <a href="https://learn.sparkfun.com/tutorials/lorawan-with-prorf-and-the-things-network">
    <figure markdown>
    LoRaWAN with ProRF and The Things Network
    </figure>
    </a>
    <a href="https://learn.sparkfun.com/tutorials/lorawan-with-prorf-and-the-things-network">**LoRaWAN with ProRF and The Things Network**
    </a>
-   <a href="https://hub.digi.com/support/products/xctu/">
    <figure markdown>
    X-CTU Software
    </figure>
    </a>
    <a href="https://hub.digi.com/support/products/xctu/">**X-CTU Software**
    </a>
</div>

<center>
<div align="center">
    <div style="top:5px;left:5px;background-color:Gray;position:relative">
        <div style="top:-5px;left:-5px;background-color:#ffffff;position:relative;border:1px solid black;">
            <a href="https://www.sparkfun.com/qwiic">Qwiic Connect System</a>
        </div>
    </div>
</div>
</center>

The SparkFun IoT Node - LoRaWAN takes advantage of the [Qwiic connect system](https://www.sparkfun.com/qwiic). We recommend familiarizing yourself with the **Logic Levels** and **I<sup>2</sup>C** tutorials.  Click on the banner above to learn more about [Qwiic products](https://www.sparkfun.com/qwiic).

<center>
    <iframe width="600" height="327" src="https://www.youtube.com/embed/x0RDEHqFIF8" title="SparkFun's Qwiic Connect System" frameborder="0" allow="accelerometer; autoplay; clipboard-write; encrypted-media; gyroscope; picture-in-picture" allowfullscreen></iframe>
</center>

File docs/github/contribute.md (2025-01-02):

# Contribute: Make an Augmentation!
Spot an improvement opportunity? Feel free to contribute to our open-source design and documentation. 

## :material-file-document-multiple:&nbsp;Improve our Documentation
All of this documentation can be modified by you! Please help us make it better.

* These pages are contained in the [`docs` folder](https://github.com/sparkfun/SparkFun_IoT_Node_LoRaWAN/tree/main/docs) of the [SparkFun IoT Node - LoRaWAN repository](https://github.com/sparkfun/https://github.com/sparkfun/SparkFun_IoT_Node_LoRaWAN/tree/main).

<!-- ### :material-source-pull:&nbsp;Submit a Correction -->
### Submit a Correction

1. With a GitHub account, [fork this repository](https://github.com/sparkfun/SparkFun_IoT_Node_LoRaWAN/fork).
2. Add your corrections or improvements to the markdown file.
3. File a pull request with your changes, and enjoy making the ~~words~~ ~~worlds~~ world a better place.
	* Once received, the documentation specialist will automatically be notified.
	* We will review your suggested improvements to make sure they are correct and fit within our documentation standards.

## :material-cog:&nbsp;Improve our Hardware Design
All of our designs are open-source! Please help us make it better.

* Our board design files are contained in the [`Hardware` folder](https://github.com/sparkfun/SparkFun_IoT_Node_LoRaWAN/tree/main/Hardware) of the [SparkFun IoT Node - LoRaWAN repository](https://github.com/sparkfun/SparkFun_IoT_Node_LoRaWAN/tree/main).

<!-- ### :material-source-pull:&nbsp;Submit a Design Enhancement -->
### Submit a Design Enhancement

1. With a GitHub account, [fork this repository](https://github.com/sparkfun/SparkFun_IoT_Node_LoRaWAN/fork).
2. Add your design augmentation(s)
3. File a pull request with your changes, and enjoy making the ~~words~~ ~~worlds~~ world a better place.
	1. Once received, the engineer in charge of the original design will automatically be notified.
	2. We will review your suggested improvement(s) to verify that they are within our board design standards and meet our product design requirements.
	3. If approved, we will flag these changes for our next board revision. Congrats! 🍻

		!!! info
			Even if your suggestion is accepted, these changes may not be immediately available for purchase. We may have to cycle through our current product inventory first.

## Contributors&nbsp;:clap:
Let's provide some recognition to the contributors for this project!

GitHub Contributors Image
<br>


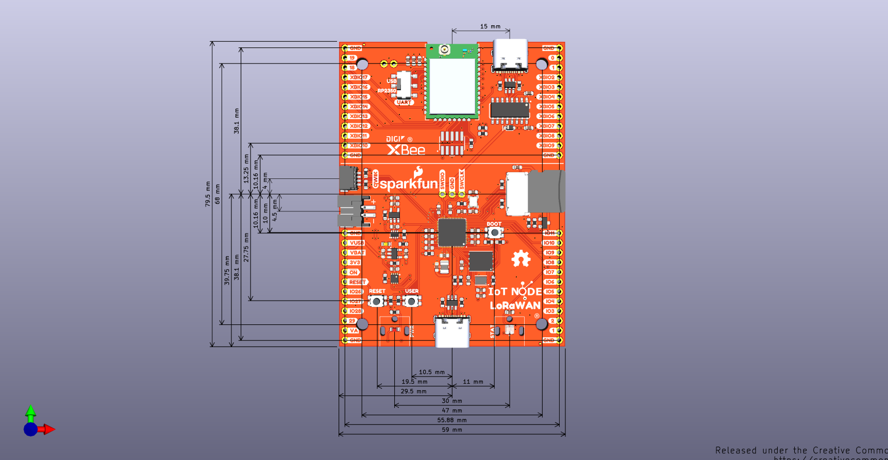
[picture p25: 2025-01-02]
docs/assets/img/SparkFun_IoT_Node_LoRaWAN.png

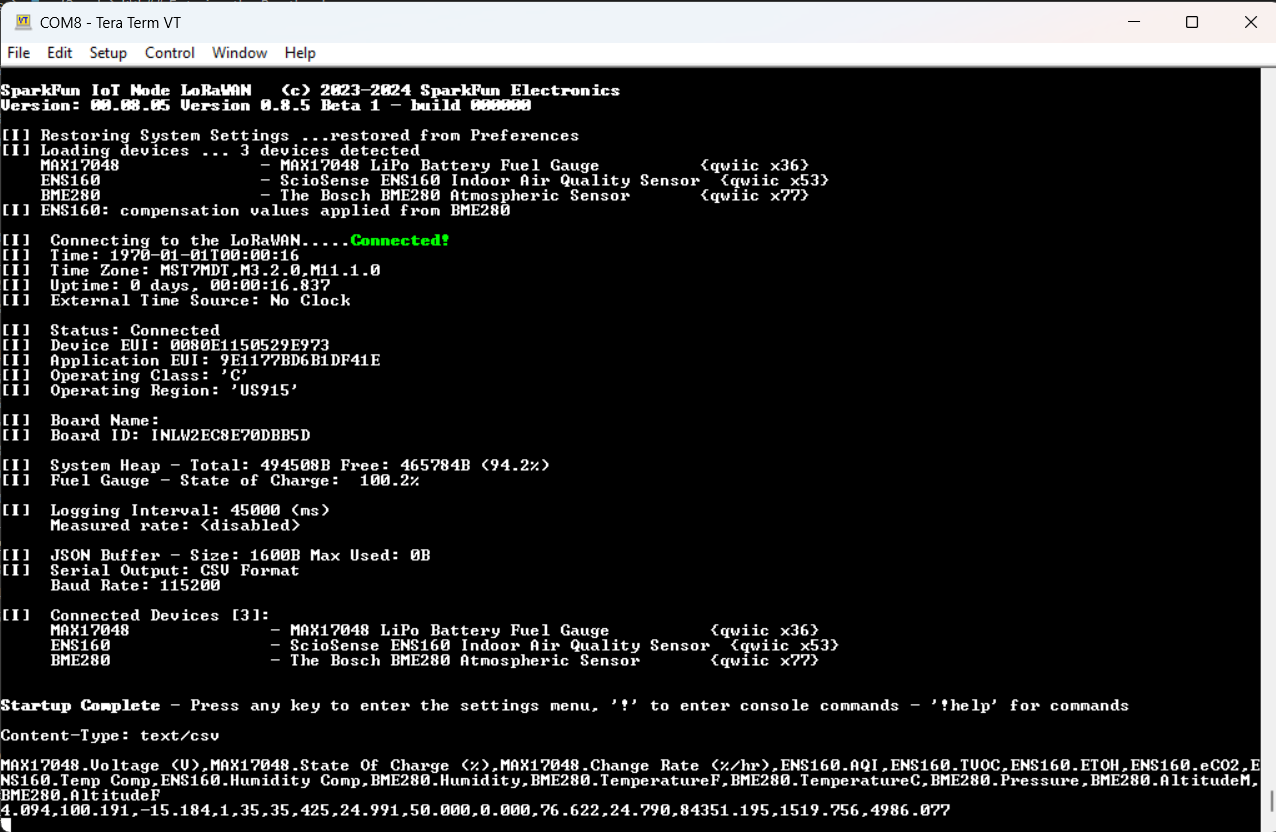
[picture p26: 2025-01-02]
docs/assets/img/LoRaWAN_Connected.png

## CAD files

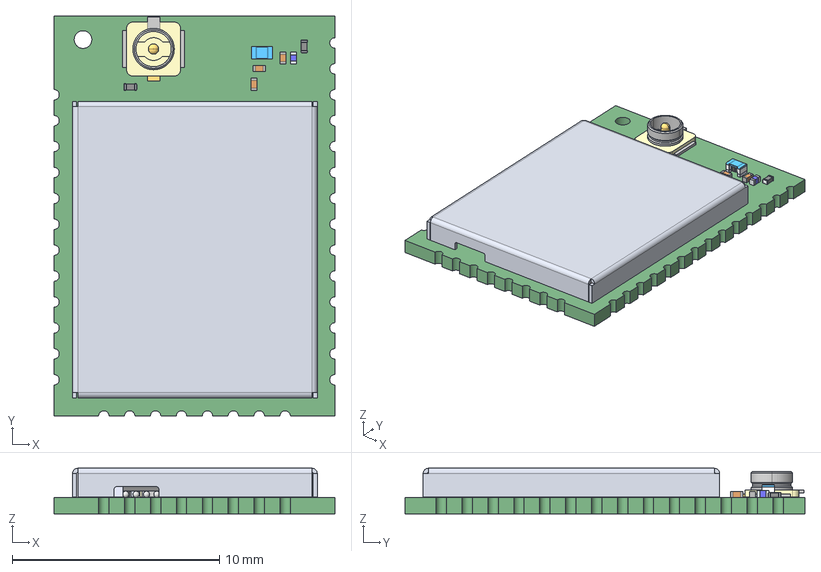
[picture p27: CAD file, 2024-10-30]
Hardware/SparkFun_IoT_Node_LoRaWAN_3D_Models/XBLR_UFL.step
13.6 x 19.3 x 2.20 mm
User Library-Resistors0201 x 9
User Library-CapacitorCap0201 x 41
0402 Ferrite bead
User Library-NT2016SA-END4910A-48MHZ Crystal (NDK)
User Library-TXC 9HT11 v1
BGS125N6
term1
term2
LQP03HQ3N6B02D x 2
LQW15AN8N7H00D x 3
0603 Ferrite bead x 2
60001461-01_A
18000258_U.FL-R-SMT-1

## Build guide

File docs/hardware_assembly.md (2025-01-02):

---
icon: fontawesome/solid/screwdriver-wrench
---

Using the Qwiic system, assembling the hardware is simple. Connect the Qwiic sensor to the SparkFun IoT Node for LoRaWAN® board using a Qwiic cable. Then connect the SparkFun IoT Node for LoRaWAN® board to your computer via the USB-C cable.  

<figure markdown>
LoRaWAN connected to Qwiic board
<figcaption markdown>Connecting a Qwiic Sensor to the SparkFun IoT Node for LoRaWAN® Board</figcaption>
</figure>

You'll also need to connect your antenna to the XBee module on the board like so: 

<figure markdown>
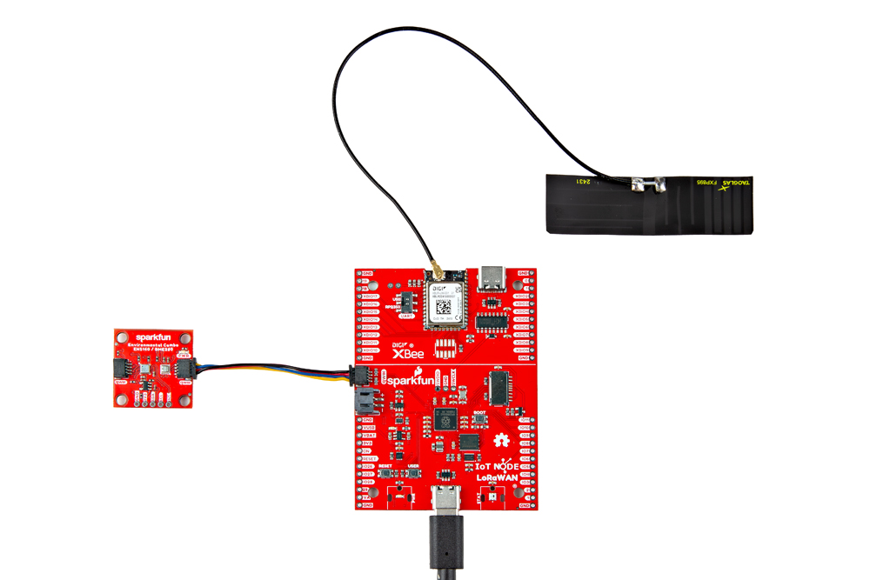
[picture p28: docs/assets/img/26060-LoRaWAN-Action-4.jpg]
Antenna connected to XBee module

<figcaption markdown>Antenna Connected to XBee module</figcaption>
</figure>

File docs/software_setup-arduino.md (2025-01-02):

---
icon: simple/arduino
---

!!! attention
	If this is your first time using Arduino, please review our tutorial on [installing the Arduino IDE](https://learn.sparkfun.com/tutorials/installing-arduino-ide). If you have not previously installed an Arduino library, please check out our [installation guide](https://learn.sparkfun.com/tutorials/installing-an-arduino-library).

<center>
	[SparkFun Ultrasonic Distance Sensor Qwiic Arduino Library GitHub](https://github.com/sparkfun/SparkFun_Qwiic_Ultrasonic_Arduino_Library/archive/refs/heads/v10.zip){ .md-button .md-button--primary }
</center>

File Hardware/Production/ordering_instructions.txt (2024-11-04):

Ordering Instructions:
Panel dimensions: 132.20 x 188.44 mm.
Controlled Impedance: JLC7628
Material: TG155
Solder Mask: Red
Silkscreen: White
Layers: 4
Finish: Lead Free HASL
Thickness: 1.6mm
Inner Copper Weight: 0.5oz
Outer Copper Weight: 1oz
Minimum track width: 0.20mm (7.87mil)
Minimum via drill: 0.30mm (11.81mil)
No Clean Process

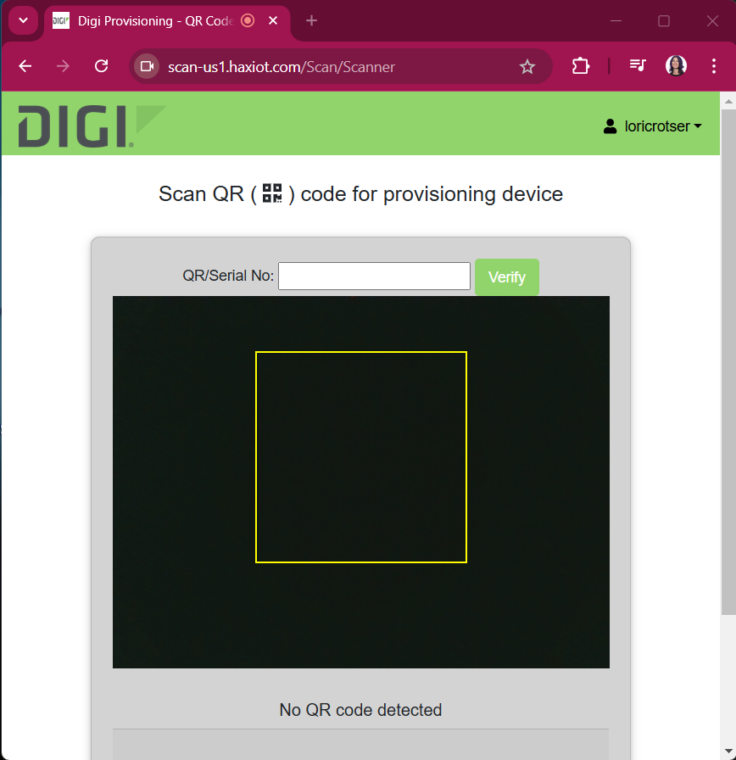
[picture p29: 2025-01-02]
docs/assets/img/ScanningPageManualIDEntry.png

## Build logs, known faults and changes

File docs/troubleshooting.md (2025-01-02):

---
icon: fontawesome/solid/question
---

!!! note
    <span class="glyphicon glyphicon-question-sign" aria-hidden="true"></span>
        <strong> Not working as expected and need help? </strong> <br /><br />

    If you need technical assistance and more information on a product that is not working as you expected, we recommend heading on over to the <a href="https://www.sparkfun.com/technical_assistance">SparkFun Technical Assistance</a> page for some initial troubleshooting. <br /><br />

    <div style="text-align: center"><a href="https://www.sparkfun.com/technical_assistance" target="sfe_technical_assistance" class="md-button">SparkFun Technical Assistance Page</a></div>

    If you don't find what you need there, the <a href="https://forum.sparkfun.com/index.php">SparkFun Forums</a> are a great place to find and ask for help. If this is your first visit, you'll need to <a href="https://forum.sparkfun.com/ucp.php?mode=register">create a Forum Account</a> to search product forums and post questions.<br /><br />

    <div style="text-align: center"><a href="https://forum.sparkfun.com/ucp.php?mode=register" class="md-button">Create New Forum Account</a>&nbsp;&nbsp;&nbsp;<a href="https://forum.sparkfun.com/index.php" class="md-button md-button--primary">Log Into SparkFun Forums</a></div>

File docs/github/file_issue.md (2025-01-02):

# Did we make a mistake?

Spot something wrong? Please let us know. 

<!-- Technical Assistance Box -->
!!! warning "Need Help?"
    If you need technical assistance or more information on a product that is not working as you expected, we recommend heading on over to the [SparkFun Technical Assistance](https://www.sparkfun.com/technical_assistanc) page for some initial troubleshooting. This **Submit Issues** page is not where users should seek assistance.

    <center>
    [SparkFun Technical Assistance Page](https://www.sparkfun.com/technical_assistance){ .md-button .md-button--primary }
    </center>
    
    If you can't find what you need there, the [SparkFun Forums](https://forum.sparkfun.com/index.php) is a great place to search the product forums and ask questions.
    
    !!! info "Account Registration Required"
        For your first visit to our forum, you'll need to create a [Forum Account](https://forum.sparkfun.com/ucp.php?mode=register) to post questions.

## Discrepancies in the Documentation

All of our documentation can be modified by you! Please help us make it better.

* The documentation files for these pages are contained in the [`docs` folder](https://github.com/sparkfun/SparkFun_IoT_Node_LoRaWAN/tree/main/docs) of the [SparkFun IoT Node - LoRaWAN repository](https://github.com/sparkfun/SparkFun_IoT_Node_LoRaWAN/tree/main).

### 🔍 Spot something wrong?

If a section of the documentation is incorrect, please [open an issue](https://github.com/sparkfun/SparkFun_IoT_Node_LoRaWAN/issues) and let us know.

### Do you have a suggested correction?

1. With a GitHub account, [fork this repository](https://github.com/sparkfun/SparkFun_IoT_Node_LoRaWAN/fork).
2. Add your correction(s) or improvement(s) to the markdown file(s)
3. File a pull request with your changes, and enjoy making the ~~words~~ ~~worlds~~ world a better place.
	* Once received, the documentation specialist will automatically be notified.
	* We will review your suggested improvement(s) to make sure they are correct and fit within our documentation standards.

## Problems in the Hardware Design

All of our designs are open-source! Please help us make it better.

* Our board design files are contained in the [`Hardware` folder](https://github.com/sparkfun/SparkFun_IoT_Node_LoRaWAN/tree/main/Hardware) of the [SparkFun IoT Node - LoRaWAN repository](https://github.com/sparkfun/SparkFun_IoT_Node_LoRaWAN/tree/main).

### Does something not make sense? 🤔

If part of the design is confusing, please [open an issue](https://github.com/sparkfun/SparkFun_IoT_Node_LoRaWAN/issues) and let us know.

### Did we forget to include an important function of the board? 🤦

If part of the board's functionality is missing, please [open an issue](https://github.com/sparkfun/SparkFun_IoT_Node_LoRaWAN/issues) and file a feature request.

!!! tip "Design Considerations"
	Please keep in mind that we may intentionally exclude certain functions of the board to meet our product design requirements.
	
	* *For example, our Qwiic Micro boards are intended to fit on a small board layout and only use I<sup>2</sup>C communication; therefore, we may not have the SPI and interrupt pins available for users.*

### Do you wish to contribute directly to improving the board design?

1. With a GitHub account, [fork this repository](https://github.com/sparkfun/SparkFun_IoT_Node_LoRaWAN/fork).
2. Add your design augmentation(s)
3. File a pull request with your changes, and enjoy making the ~~words~~ ~~worlds~~ world a better place.
	1. Once received, the engineer in charge of the original design will automatically be notified.
	2. We will review your suggested improvement(s) to verify that they are within our board design standards and meet our product design requirements.
	3. If approved, we will flag these changes for our next board revision. Congrats! 🍻

		!!! info
			Even if your suggestion is accepted, these changes may not be immediately available for purchase. We may have to cycle through our current product inventory first.

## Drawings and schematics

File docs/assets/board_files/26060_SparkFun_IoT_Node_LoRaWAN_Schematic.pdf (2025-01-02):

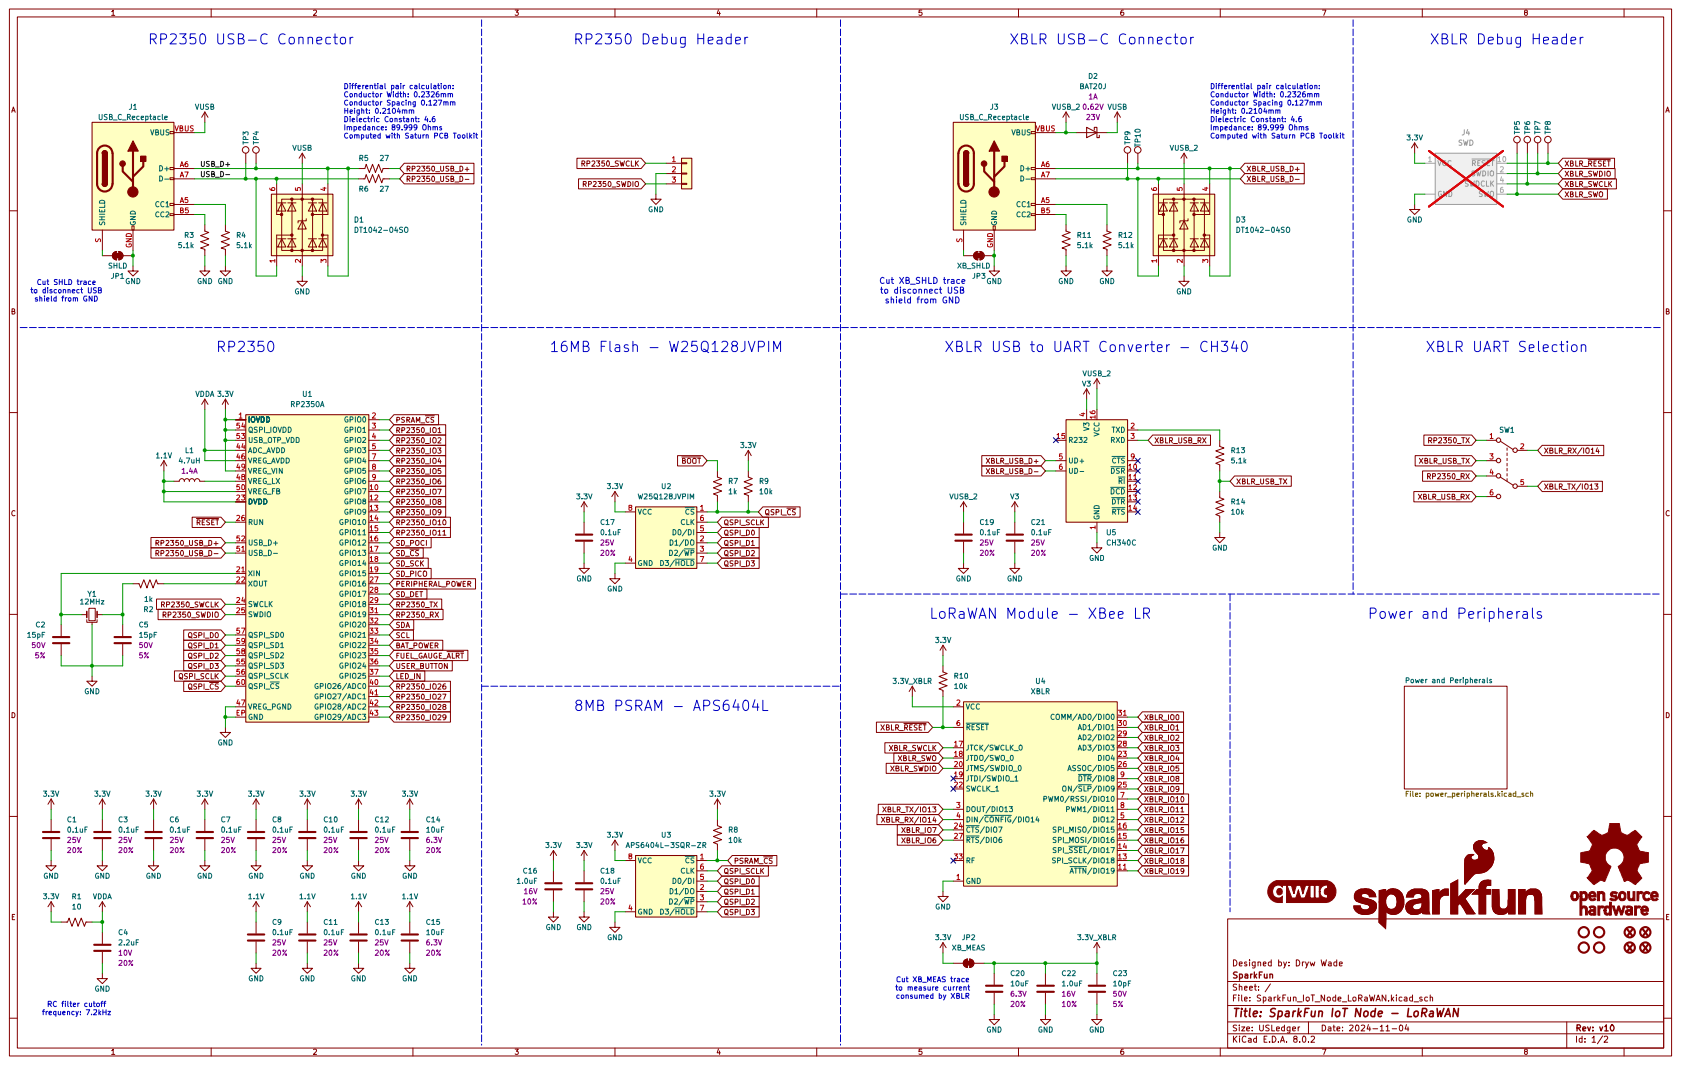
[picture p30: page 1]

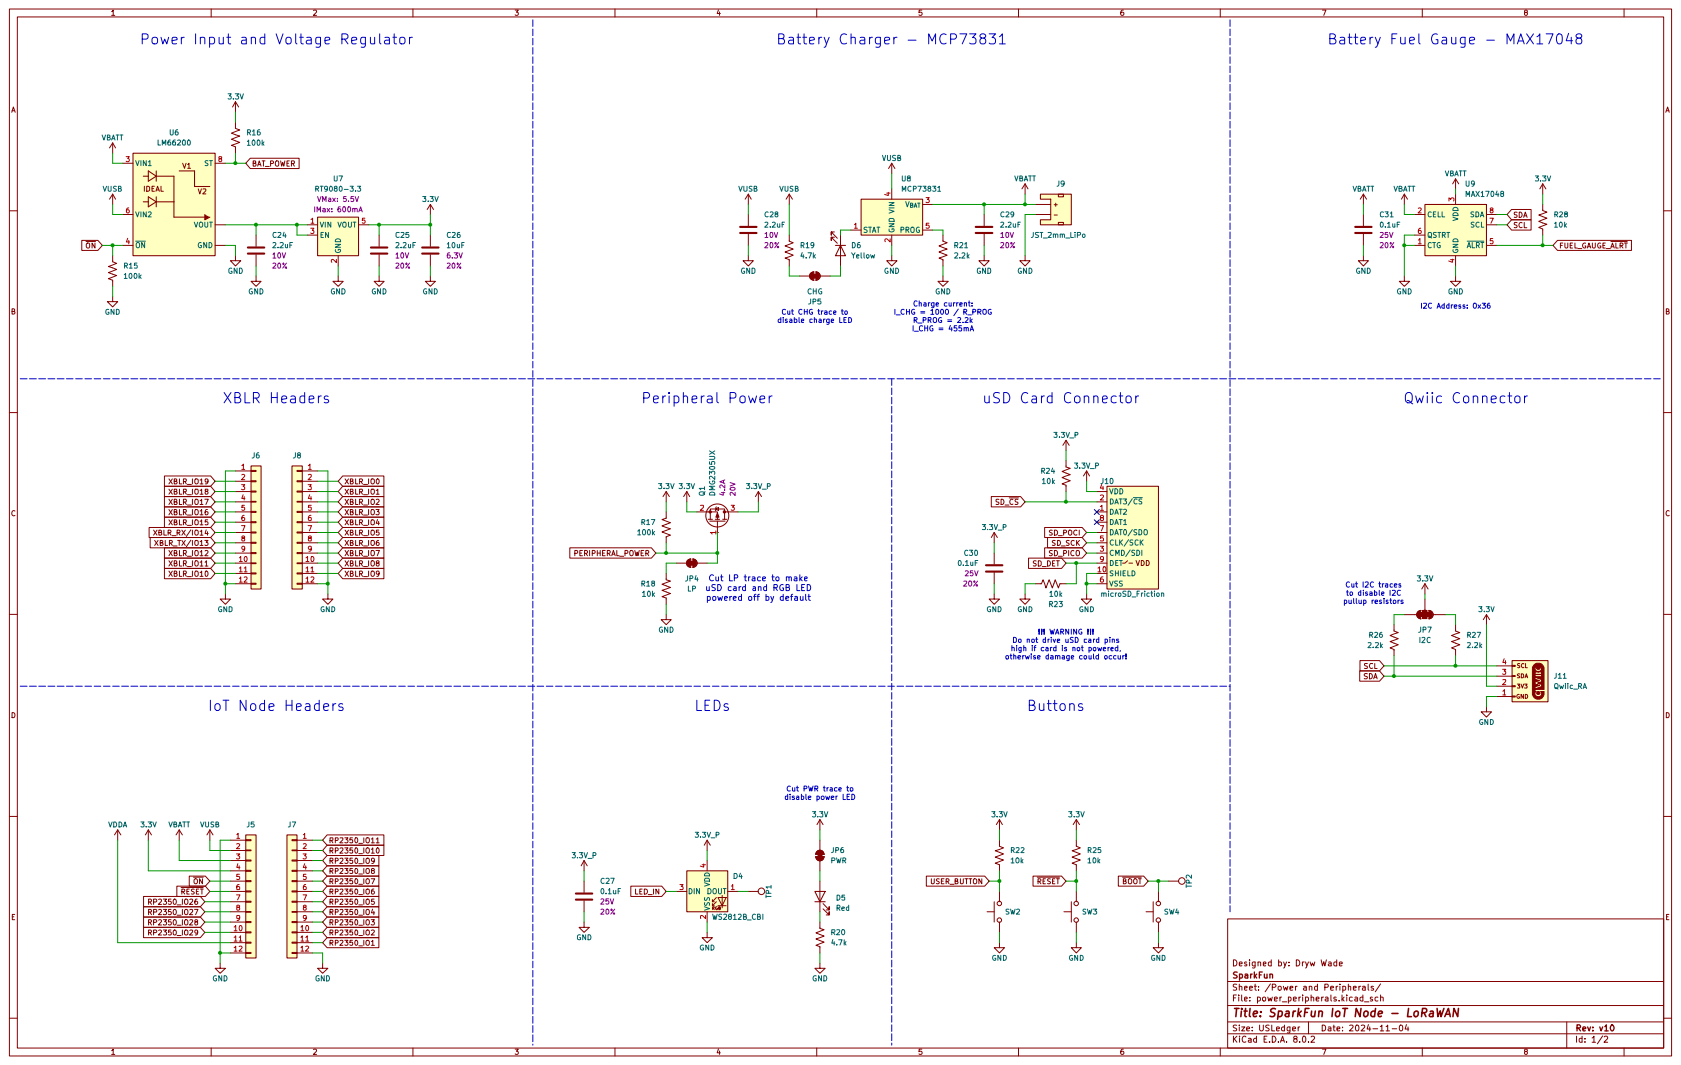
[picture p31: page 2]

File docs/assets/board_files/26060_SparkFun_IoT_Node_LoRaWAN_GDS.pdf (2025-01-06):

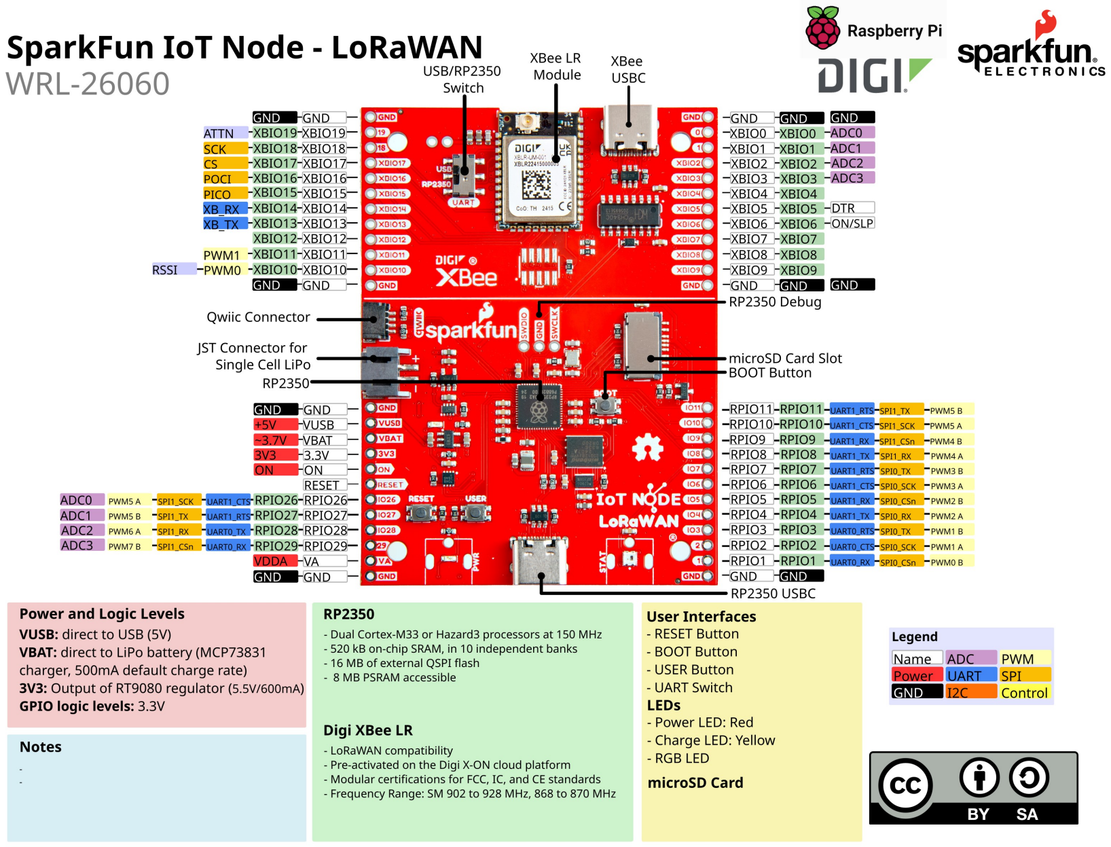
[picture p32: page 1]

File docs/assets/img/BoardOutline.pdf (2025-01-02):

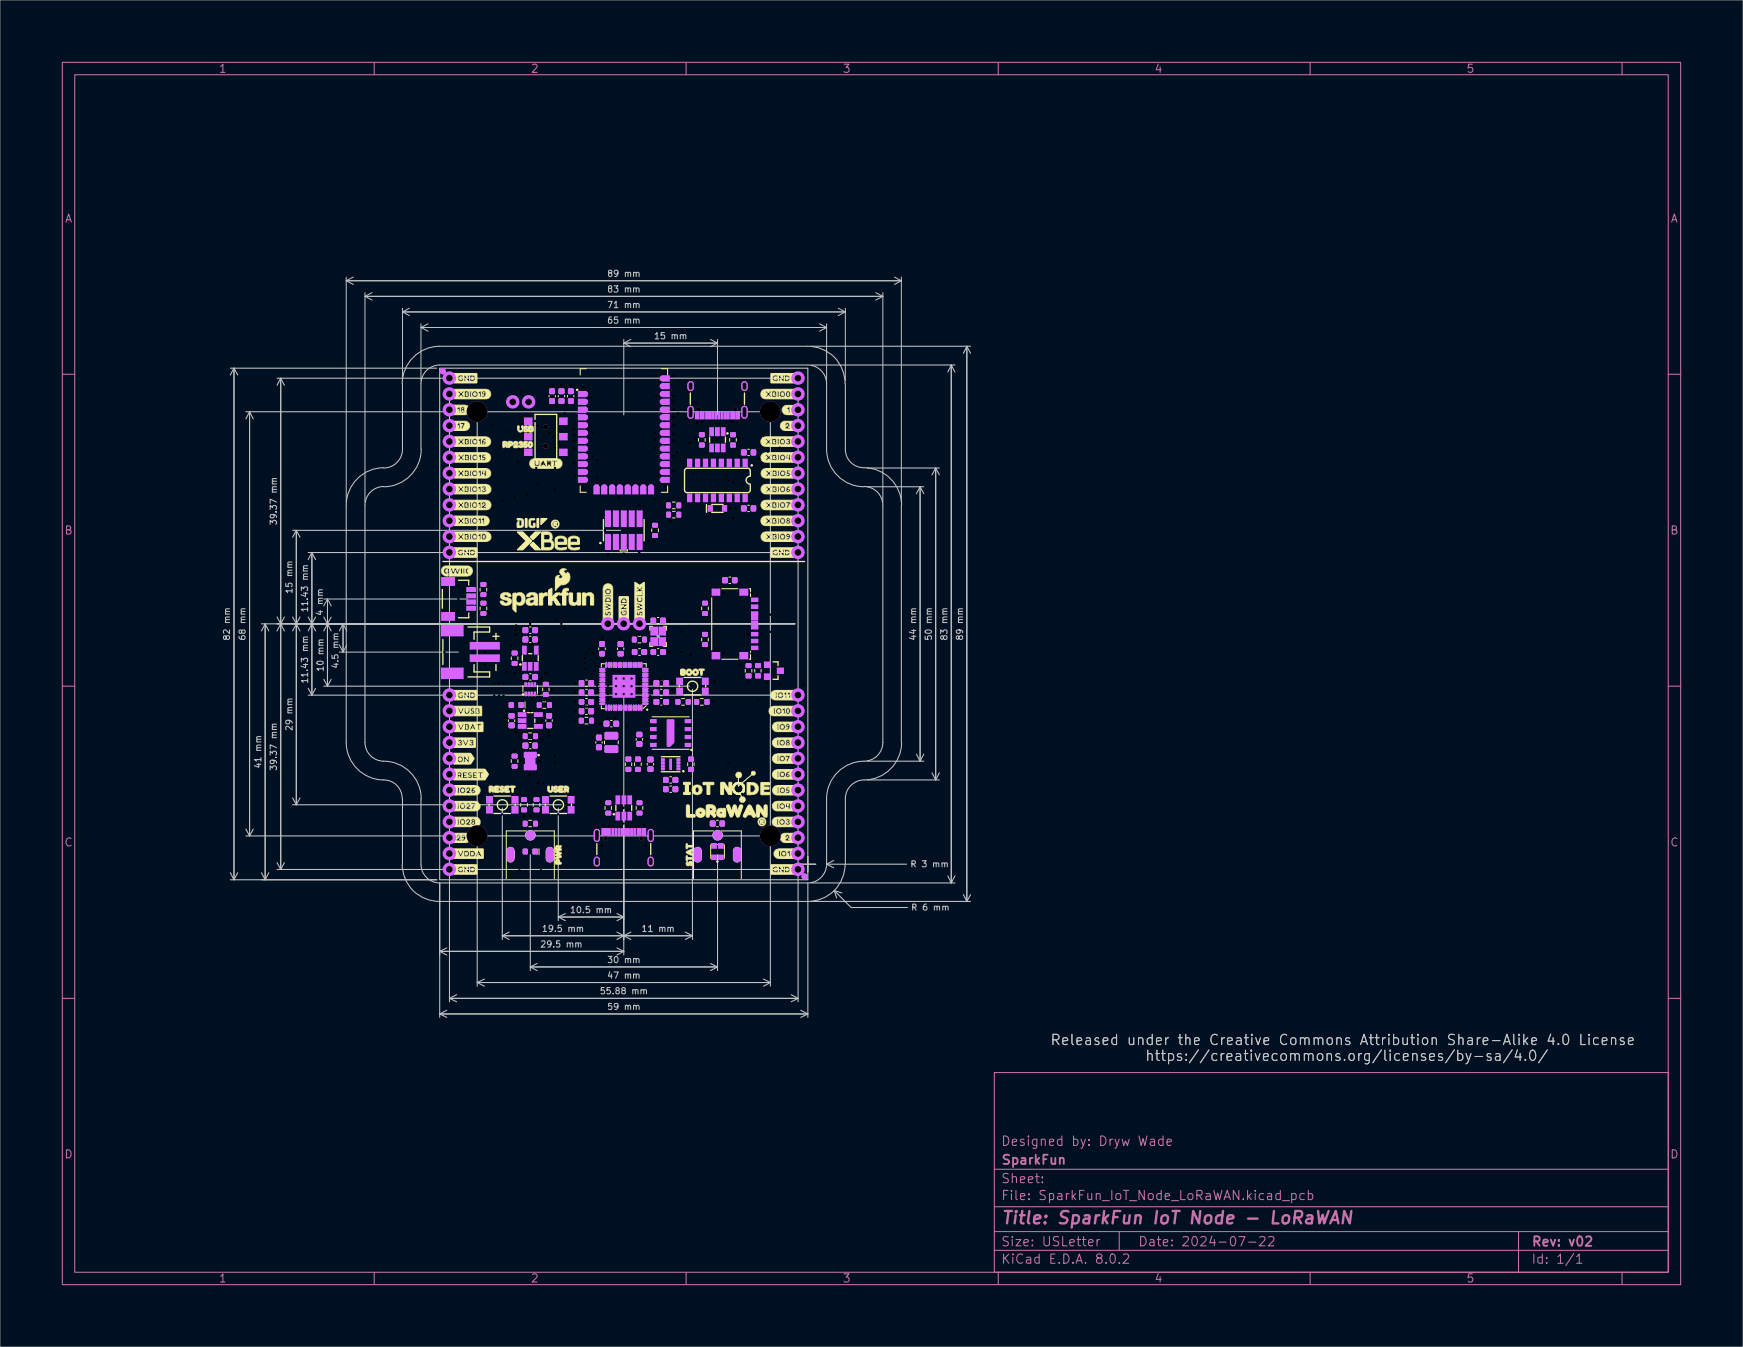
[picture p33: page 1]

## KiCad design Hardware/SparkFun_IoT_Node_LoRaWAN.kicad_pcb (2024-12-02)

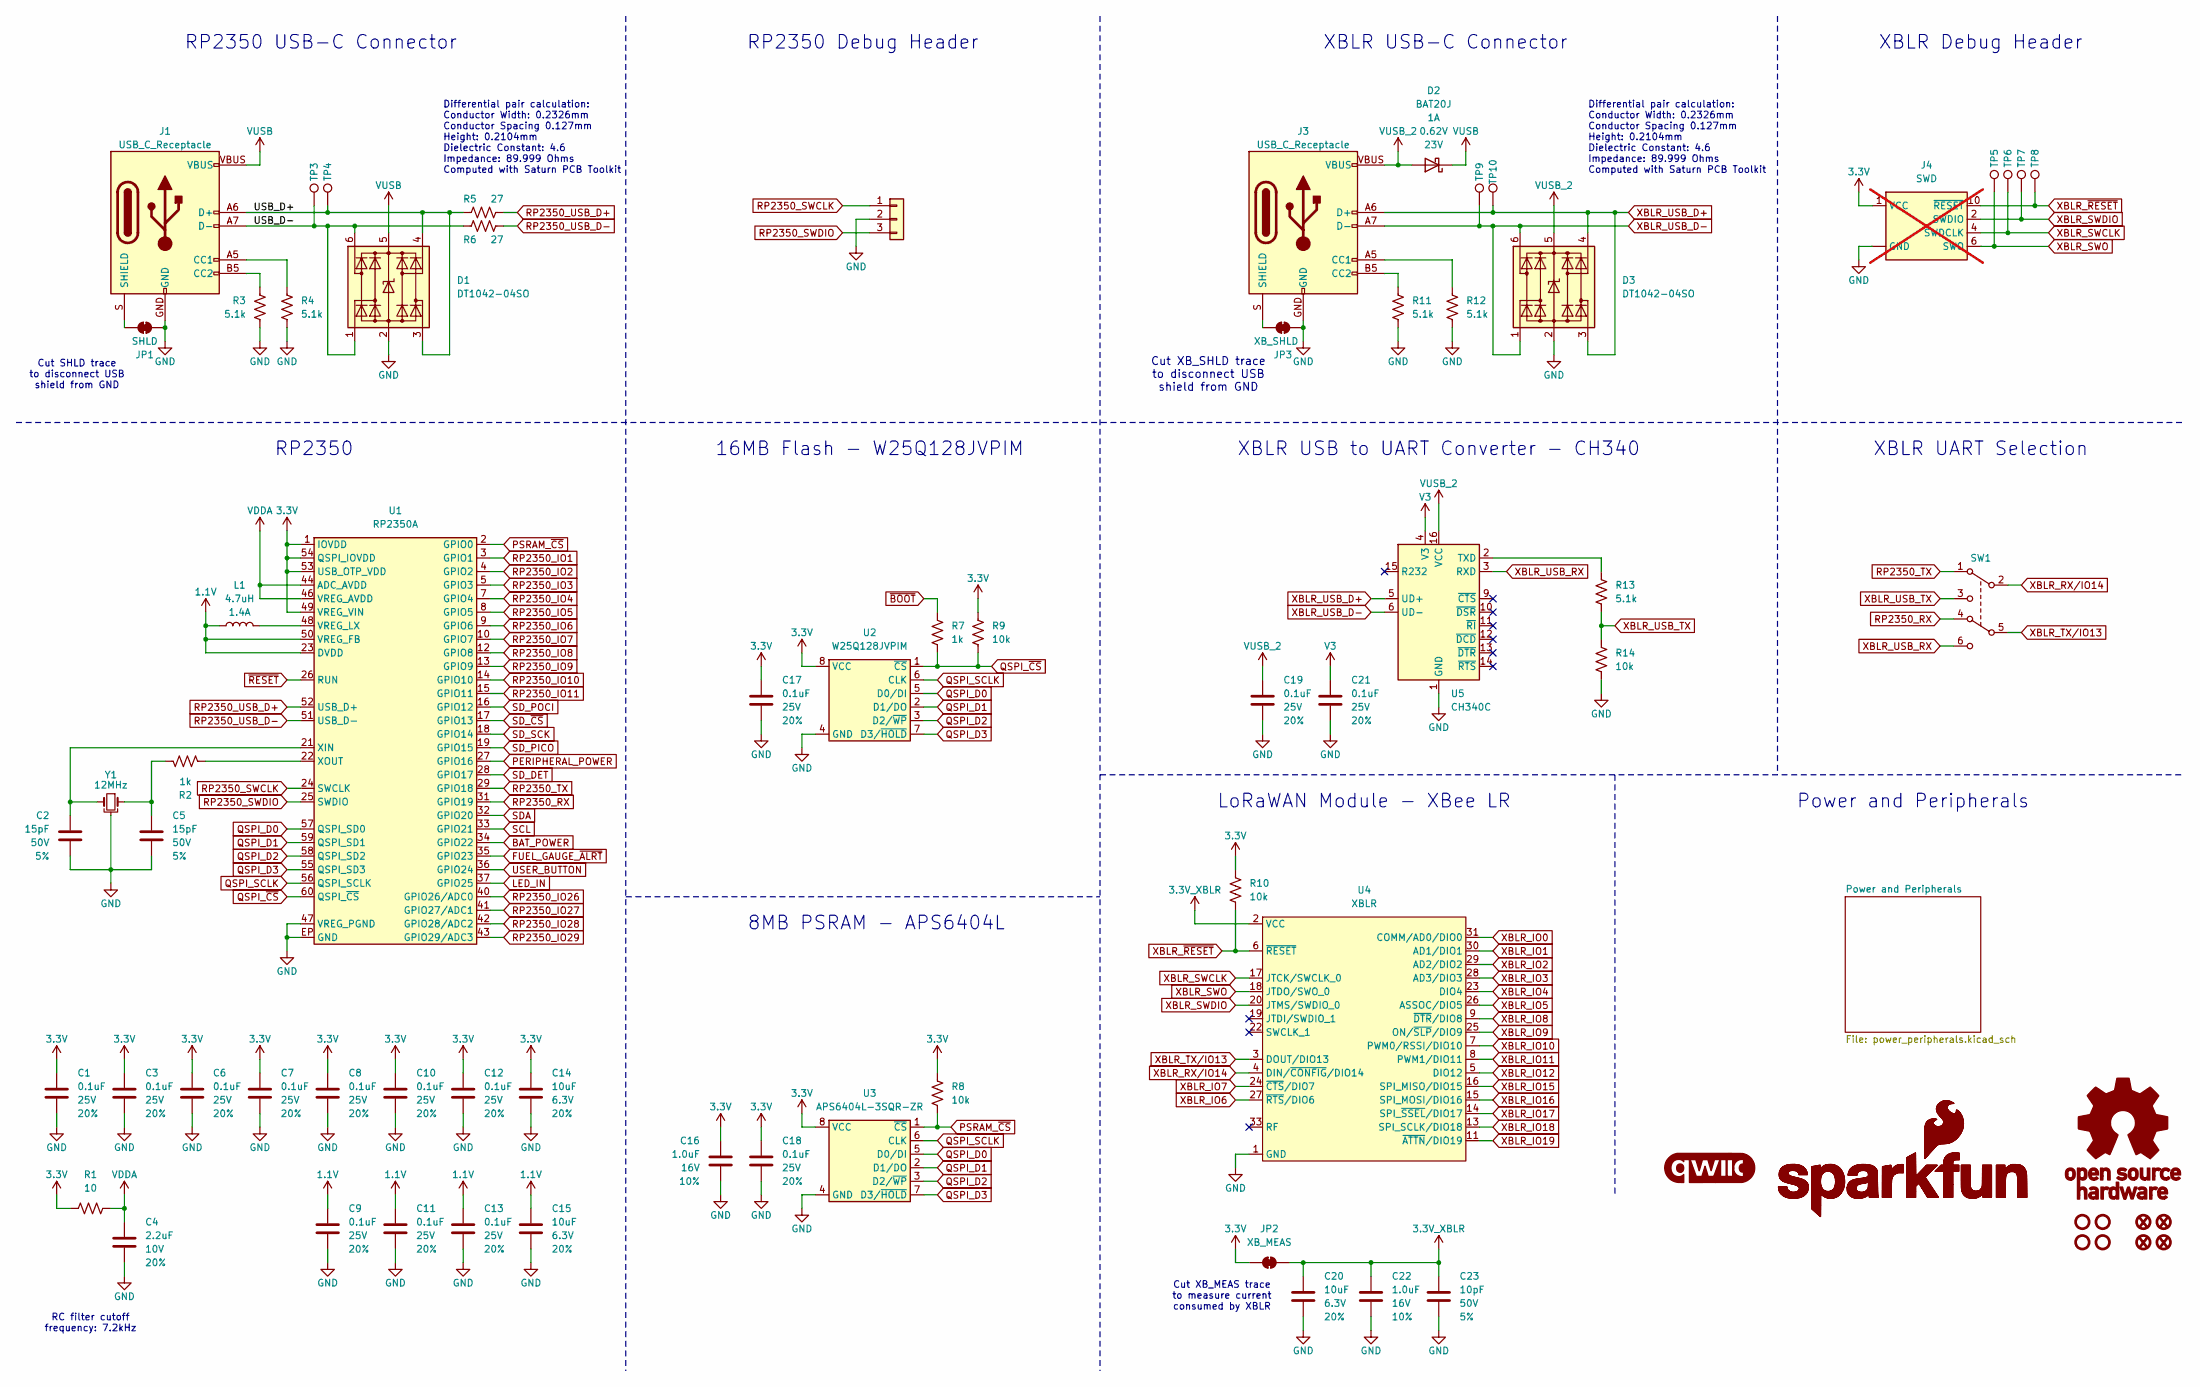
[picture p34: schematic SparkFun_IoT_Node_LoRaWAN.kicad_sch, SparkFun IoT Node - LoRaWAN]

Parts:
C1, C3, C6, C7, C8, C9, C10, C11, C12, C13, C17, C18, C19, C21: 0.1uF; C_0603_1608Metric; Voltage 25V; Tolerance 20%
C2, C5: 15pF; C_0603_1608Metric; Voltage 50V; Tolerance 5%
C4: 2.2uF; C_0603_1608Metric; Voltage 10V; Tolerance 20%
C14, C15, C20: 10uF; C_0603_1608Metric; Voltage 6.3V; Tolerance 20%
C16, C22: 1.0uF; C_0603_1608Metric; Voltage 16V; Tolerance 10%
C23: 10pF; C_0603_1608Metric; Voltage 50V; Tolerance 5%
D1, D3: DT1042-04SO; SOT23-6
D2: BAT20J; SOD-323
FID1, FID2, FID3, FID4: Fiducial_0.5mm; Fiducial_0.5mm_Mask1mm
G1: qwiic_Logo
G2: SparkFun_Logo; SparkFun_Logo_8mm
G3: SparkFun_Logo
G4: OSHW_Logo; Creative_Commons_License
J1, J3: USB_C_Receptacle; USB-C_16
J2: Conn_01x03; 1x03
J4: SWD; 2x5_1.27mm_SMD_Unshrouded; not fitted
JP1: SHLD; Jumper_2_NC_Trace
JP2: XB_MEAS; Jumper_2_PTH_SMD_Combo-NC
JP3: XB_SHLD; Jumper_2_NC_Trace
L1: 4.7uH; 1008_2520Metric
R1: 10; R_0603_1608Metric
R2, R7: 1k; R_0603_1608Metric
R3, R4, R11, R12, R13: 5.1k; R_0603_1608Metric
R5, R6: 27; R_0603_1608Metric
R8, R9, R10, R14: 10k; R_0603_1608Metric
ST1, ST2, ST3, ST4: Standoff
SW1: DPDT_Slide_SMD_7.2x3.5mm; Slide_DPDT_SMD_7.2x3.5mm; Mfg Part# ABC
TP3, TP4, TP5, TP6, TP7, TP8, TP9, TP10: 1.0mm; TestPoint-1.0mm
U1: RP2350A; QFN-60-1EP_7x7mm_P0.4mm_EP3.5x3.5mm
U2: W25Q128JVPIM; WDFN-8_6x5mm-SkinnyCenterPad
U3: APS6404L-3SQR-ZR; USON-8_3x2mm-SkinnyCenterPad
U4: XBLR; XBee_LR
U5: CH340C; SO-16
Y1: 12MHz; Crystal_SMD_2.5x2.0mm

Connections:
1.1V: C9.1, C11.1, C13.1, C15.1, L1.1, U1.6 (DVDD), U1.23 (DVDD), U1.39 (DVDD), U1.50 (VREG_FB)
3.3V: C1.1, C3.1, C6.1, C7.1, C8.1, C10.1, C12.1, C14.1, C16.1, C17.1, C18.1, J4.1 (VCC), JP2.1 (A), R1.2, R8.1, R9.1, R10.1, U1.1 (IOVDD), U1.11 (IOVDD), U1.20 (IOVDD), U1.30 (IOVDD), U1.38 (IOVDD), U1.45 (IOVDD), U1.49 (VREG_VIN), U1.53 (USB_OTP_VDD), U1.54 (QSPI_IOVDD), U2.8 (VCC), U3.8 (VCC); also elsewhere on the board
3.3V_XBLR: C20.1, C22.1, C23.1, JP2.2 (B), U4.2 (VCC)
/USB_D+: D1.3 (I/O2), D1.4 (I/O3), J1.A6 (D+), J1.B6 (D+), R5.2, TP4.1
/USB_D-: D1.1 (I/O1), D1.6 (I/O4), J1.A7 (D-), J1.B7 (D-), R6.2, TP3.1
BAT_POWER: U1.34 (GPIO22); also elsewhere on the board
FUEL_GAUGE_~ALRT: U1.35 (GPIO23); also elsewhere on the board
GND: C1.2, C2.1, C3.2, C4.2, C5.1, C6.2, C7.2, C8.2, C9.2, C10.2, C11.2, C12.2, C13.2, C14.2, C15.2, C16.2, C17.2, C18.2, C19.2, C20.2, C21.2, C22.2, C23.2, D1.2 (GND), D3.2 (GND), J1.GND, J2.2, J3.GND, J4.3 (GND), J4.5 (GND), J4.9 (GND), JP1.2 (B), JP3.2 (B), R3.2, R4.2, R11.2, R12.2, R14.2, U1.47 (VREG_PGND), U1.EP (GND), U2.4 (GND), U3.4 (GND), U3.9 (GND), U4.1 (GND), U4.10 (GND), U4.12 (GND), U4.21 (GND), U4.32 (GND), U4.34 (GND), U5.1 (GND), Y1.2, Y1.4; also elsewhere on the board
LED_IN: U1.37 (GPIO25); also elsewhere on the board
unnamed: C5.2, R2.2, Y1.1
unnamed: J1.A5 (CC1), R4.1
unnamed: J1.B5 (CC2), R3.1
unnamed: J1.S (SHIELD), JP1.1 (A)
unnamed: J3.A5 (CC1), R12.1
unnamed: J3.B5 (CC2), R11.1
unnamed: J3.S (SHIELD), JP3.1 (A)
unnamed: L1.2, U1.48 (VREG_LX)
unnamed: C2.2, U1.21 (XIN), Y1.3
unnamed: R2.1, U1.22 (XOUT)
unnamed: R13.1, U5.2 (TXD)
PERIPHERAL_POWER: U1.27 (GPIO16); also elsewhere on the board
PSRAM_~CS: R8.2, U1.2 (GPIO0), U3.1 (~CS)
QSPI_D0: U1.57 (QSPI_SD0), U2.5 (D0/DI), U3.5 (D0/DI)
QSPI_D1: U1.59 (QSPI_SD1), U2.2 (D1/DO), U3.2 (D1/DO)
QSPI_D2: U1.58 (QSPI_SD2), U2.3 (D2/~WP), U3.3 (D2/~WP)
QSPI_D3: U1.55 (QSPI_SD3), U2.7 (D3/~HOLD), U3.7 (D3/~HOLD)
QSPI_SCLK: U1.56 (QSPI_SCLK), U2.6 (CLK), U3.6 (CLK)
QSPI_~CS: R7.2, R9.2, U1.60 (QSPI_~CS), U2.1 (~CS)
RP2350_IO1: U1.3 (GPIO1); also elsewhere on the board
RP2350_IO2: U1.4 (GPIO2); also elsewhere on the board
RP2350_IO3: U1.5 (GPIO3); also elsewhere on the board
RP2350_IO4: U1.7 (GPIO4); also elsewhere on the board
RP2350_IO5: U1.8 (GPIO5); also elsewhere on the board
RP2350_IO6: U1.9 (GPIO6); also elsewhere on the board
RP2350_IO7: U1.10 (GPIO7); also elsewhere on the board
RP2350_IO8: U1.12 (GPIO8); also elsewhere on the board
RP2350_IO9: U1.13 (GPIO9); also elsewhere on the board
RP2350_IO10: U1.14 (GPIO10); also elsewhere on the board
RP2350_IO11: U1.15 (GPIO11); also elsewhere on the board
RP2350_IO26: U1.40 (GPIO26/ADC0); also elsewhere on the board
RP2350_IO27: U1.41 (GPIO27/ADC1); also elsewhere on the board
RP2350_IO28: U1.42 (GPIO28/ADC2); also elsewhere on the board
RP2350_IO29: U1.43 (GPIO29/ADC3); also elsewhere on the board
RP2350_RX: SW1.4 (A), U1.31 (GPIO19)
RP2350_SWCLK: J2.1, U1.24 (SWCLK)
RP2350_SWDIO: J2.3, U1.25 (SWDIO)
RP2350_TX: SW1.1 (A), U1.29 (GPIO18)
RP2350_USB_D+: R5.1, U1.52 (USB_D+)
RP2350_USB_D-: R6.1, U1.51 (USB_D-)
SCL: U1.33 (GPIO21); also elsewhere on the board
SDA: U1.32 (GPIO20); also elsewhere on the board
SD_DET: U1.28 (GPIO17); also elsewhere on the board
SD_PICO: U1.19 (GPIO15); also elsewhere on the board
SD_POCI: U1.16 (GPIO12); also elsewhere on the board
SD_SCK: U1.18 (GPIO14); also elsewhere on the board
SD_~CS: U1.17 (GPIO13); also elsewhere on the board
USER_BUTTON: U1.36 (GPIO24); also elsewhere on the board
V3: C21.1, U5.4 (V3)
VDDA: C4.1, R1.1, U1.44 (ADC_AVDD), U1.46 (VREG_AVDD); also elsewhere on the board
VUSB: D1.5 (VCC), D2.C, J1.VBUS; also elsewhere on the board
VUSB_2: C19.1, D2.A, D3.5 (VCC), J3.VBUS, U5.16 (VCC)
XBLR_IO0: U4.31 (COMM/AD0/DIO0); also elsewhere on the board
XBLR_IO1: U4.30 (AD1/DIO1); also elsewhere on the board
XBLR_IO2: U4.29 (AD2/DIO2); also elsewhere on the board
XBLR_IO3: U4.28 (AD3/DIO3); also elsewhere on the board
XBLR_IO4: U4.23 (DIO4); also elsewhere on the board
XBLR_IO5: U4.26 (ASSOC/DIO5); also elsewhere on the board
XBLR_IO6: U4.27 (~RTS/DIO6); also elsewhere on the board
XBLR_IO7: U4.24 (~CTS/DIO7); also elsewhere on the board
XBLR_IO8: U4.9 (~DTR/DIO8); also elsewhere on the board
XBLR_IO9: U4.25 (ON/~SLP/DIO9); also elsewhere on the board
XBLR_IO10: U4.7 (PWM0/RSSI/DIO10); also elsewhere on the board
XBLR_IO11: U4.8 (PWM1/DIO11); also elsewhere on the board
XBLR_IO12: U4.5 (DIO12); also elsewhere on the board
XBLR_IO15: U4.16 (SPI_MISO/DIO15); also elsewhere on the board
XBLR_IO16: U4.15 (SPI_MOSI/DIO16); also elsewhere on the board
XBLR_IO17: U4.14 (SPI_~SSEL/DIO17); also elsewhere on the board
XBLR_IO18: U4.13 (SPI_SCLK/DIO18); also elsewhere on the board
XBLR_IO19: U4.11 (~ATTN/DIO19); also elsewhere on the board
XBLR_RX/IO14: SW1.2 (B), U4.4 (DIN/~CONFIG/DIO14); also elsewhere on the board
XBLR_SWCLK: J4.4 (SWDCLK), TP6.1, U4.17 (JTCK/SWCLK_0)
XBLR_SWDIO: J4.2 (SWDIO), TP7.1, U4.20 (JTMS/SWDIO_0)
XBLR_SWO: J4.6 (SWO), TP5.1, U4.18 (JTDO/SWO_0)
XBLR_TX/IO13: SW1.5 (B), U4.3 (DOUT/DIO13); also elsewhere on the board
XBLR_USB_D+: D3.3 (I/O2), D3.4 (I/O3), J3.A6 (D+), J3.B6 (D+), TP10.1, U5.5 (UD+)
XBLR_USB_D-: D3.1 (I/O1), D3.6 (I/O4), J3.A7 (D-), J3.B7 (D-), TP9.1, U5.6 (UD-)
XBLR_USB_RX: SW1.6 (C), U5.3 (RXD)
XBLR_USB_TX: R13.2, R14.1, SW1.3 (C)
XBLR_~RESET: J4.10 (~RESET), R10.2, TP8.1, U4.6 (~RESET)
~BOOT: R7.1; also elsewhere on the board
~RESET: U1.26 (RUN); also elsewhere on the board

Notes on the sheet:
Differential pair calculation: Conductor Width: 0.2326mm Conductor Spacing 0.127mm Height: 0.2104mm Dielectric Constant: 4.6 Impedance: 89.999 Ohms Computed with Saturn PCB Toolkit
16MB Flash - W25Q128JVPIM
8MB PSRAM - APS6404L
XBLR USB-C Connector
RP2350 Debug Header
XBLR USB to UART Converter - CH340
RP2350
Cut XB_MEAS trace to measure current consumed by XBLR
Cut SHLD trace to disconnect USB shield from GND
XBLR Debug Header
RC filter cutoff frequency: 7.2kHz
Cut XB_SHLD trace to disconnect USB shield from GND
LoRaWAN Module - XBee LR
XBLR UART Selection
RP2350 USB-C Connector
Power and Peripherals

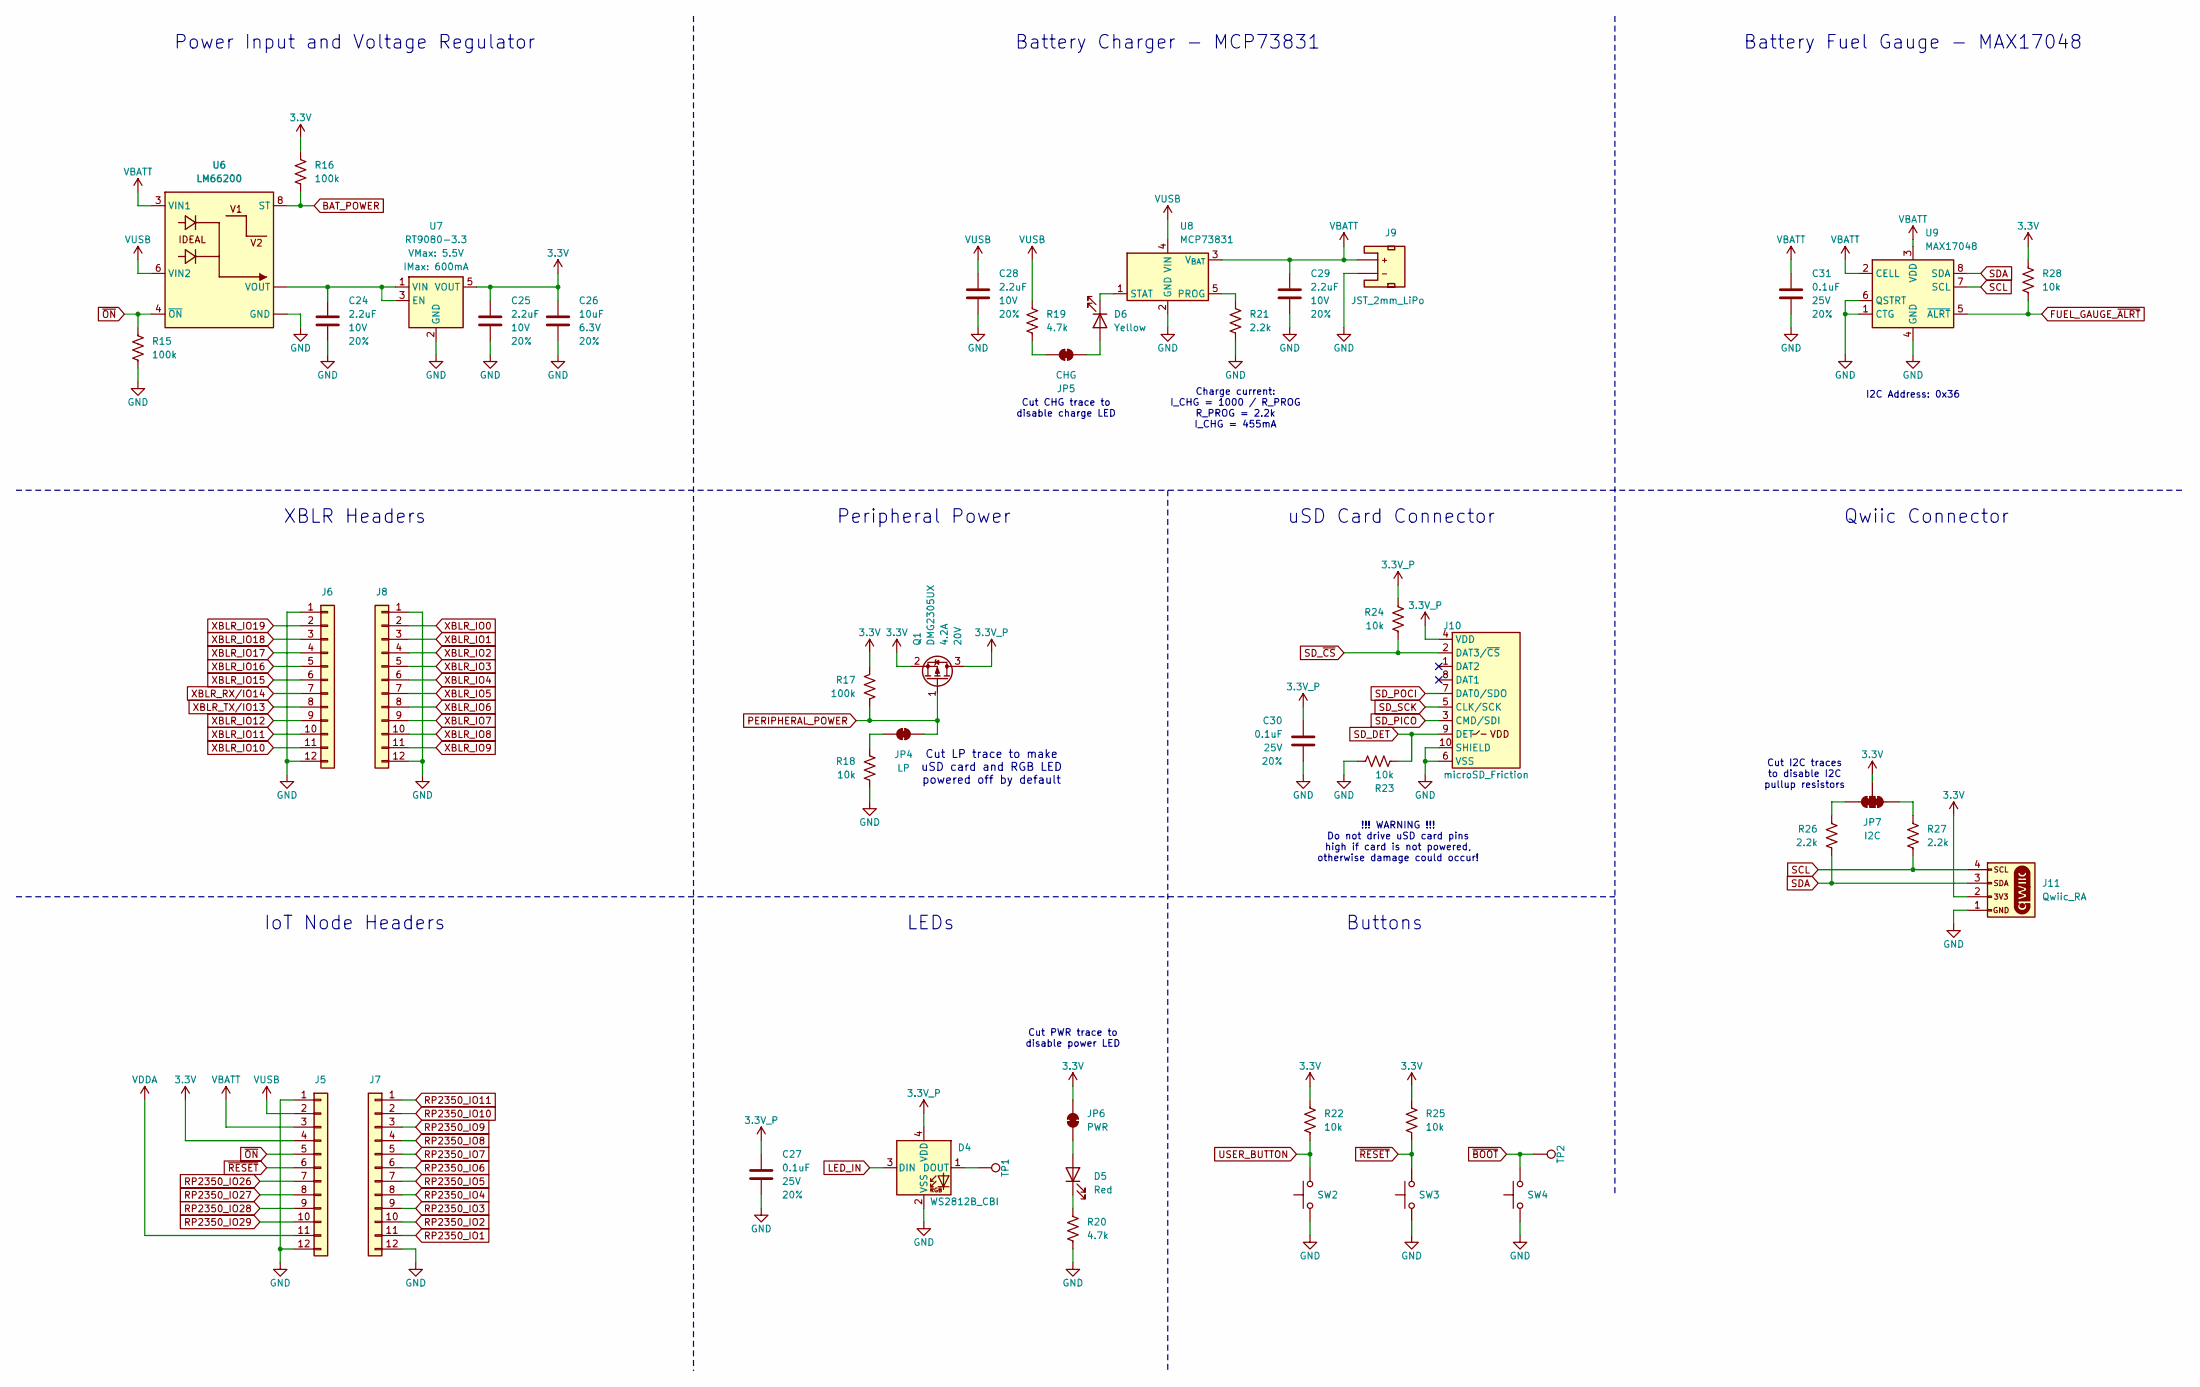
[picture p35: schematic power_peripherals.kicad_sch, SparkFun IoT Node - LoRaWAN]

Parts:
C24, C25, C28, C29: 2.2uF; C_0603_1608Metric; Voltage 10V; Tolerance 20%
C26: 10uF; C_0603_1608Metric; Voltage 6.3V; Tolerance 20%
C27, C30, C31: 0.1uF; C_0603_1608Metric; Voltage 25V; Tolerance 20%
D4: WS2812B_CBI; WS2812_2020
D5: Red; LED_0603_1608Metric_Red
D6: Yellow; LED_0603_1608Metric_Yellow
J5, J6, J7, J8: Conn_01x10; 1x12
J9: JST_2mm_LiPo; JST_SMD_2.0mm-2
J10: microSD_Friction; microSD_Friction_Fit_Common
J11: Qwiic_RA; JST_SMD_1.0mm-4_RA
JP4: LP; Jumper_2_NC_Trace
JP5: CHG; Jumper_2_NC_Trace
JP6: PWR; Jumper_2_NC_Trace
JP7: I2C; Jumper_3_NC-2_Trace
Q1: DMG2305UX; SOT23-3
R15, R16, R17: 100k; R_0603_1608Metric
R18, R22, R23, R24, R25, R28: 10k; R_0603_1608Metric
R19, R20: 4.7k; R_0603_1608Metric
R21, R26, R27: 2.2k; R_0603_1608Metric
SW2, SW3, SW4: SMD_4.6x2.8mm_h2.5mm; Push_SMD_4.6x2.8mm_h2.5mm
TP1, TP2: 1.0mm; TestPoint-1.0mm
U6: LM66200; SOT-583-8
U7: RT9080-3.3; SOT23-5
U8: MCP73831; SOT23-5
U9: MAX17048; DFN-8

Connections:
3.3V: C25.1, C26.1, J5.4, J11.2, JP6.2 (B), JP7.2 (C), Q1.2 (S), R16.1, R17.1, R22.1, R25.1, R28.1, U7.5 (VOUT); also elsewhere on the board
3.3V_P: C27.1, C30.1, D4.4 (VDD), J10.4 (VDD), Q1.3 (D), R24.1
BAT_POWER: R16.2, U6.8 (ST); also elsewhere on the board
FUEL_GAUGE_~ALRT: R28.2, U9.5 (~ALRT); also elsewhere on the board
GND: C24.2, C25.2, C26.2, C27.2, C28.2, C29.2, C30.2, C31.2, D4.2 (VSS), J5.1, J5.12, J6.1, J6.12, J7.12, J8.1, J8.12, J9.1 (-), J10.6 (VSS), J10.10 (SHIELD), J11.1, R15.2, R18.2, R20.2, R21.2, R23.2, SW2.1, SW3.1, SW4.1, U6.1 (GND), U6.5 (GND), U7.2 (GND), U8.2 (GND), U9.1 (CTG), U9.4 (GND), U9.6 (QSTRT), U9.9 (GND); also elsewhere on the board
LED_IN: D4.3 (DIN); also elsewhere on the board
unnamed: D4.1 (DOUT), TP1.1
unnamed: D5.2 (A), JP6.1 (A)
unnamed: D5.1 (K), R20.1
unnamed: D6.2 (A), JP5.2 (B)
unnamed: D6.1 (K), U8.1 (STAT)
unnamed: JP4.1 (A), R18.1
unnamed: JP5.1 (A), R19.2
unnamed: JP7.1 (A), R27.1
unnamed: JP7.3 (B), R26.1
unnamed: C24.1, U6.2 (VOUT), U6.7 (VOUT), U7.1 (VIN), U7.3 (EN)
unnamed: R21.1, U8.5 (PROG)
PERIPHERAL_POWER: JP4.2 (B), Q1.1 (G), R17.2; also elsewhere on the board
RP2350_IO1: J7.11; also elsewhere on the board
RP2350_IO2: J7.10; also elsewhere on the board
RP2350_IO3: J7.9; also elsewhere on the board
RP2350_IO4: J7.8; also elsewhere on the board
RP2350_IO5: J7.7; also elsewhere on the board
RP2350_IO6: J7.6; also elsewhere on the board
RP2350_IO7: J7.5; also elsewhere on the board
RP2350_IO8: J7.4; also elsewhere on the board
RP2350_IO9: J7.3; also elsewhere on the board
RP2350_IO10: J7.2; also elsewhere on the board
RP2350_IO11: J7.1; also elsewhere on the board
RP2350_IO26: J5.7; also elsewhere on the board
RP2350_IO27: J5.8; also elsewhere on the board
RP2350_IO28: J5.9; also elsewhere on the board
RP2350_IO29: J5.10; also elsewhere on the board
SCL: J11.4, R27.2, U9.7 (SCL); also elsewhere on the board
SDA: J11.3, R26.2, U9.8 (SDA); also elsewhere on the board
SD_DET: J10.9 (DET), R23.1; also elsewhere on the board
SD_PICO: J10.3 (CMD/SDI); also elsewhere on the board
SD_POCI: J10.7 (DAT0/SDO); also elsewhere on the board
SD_SCK: J10.5 (CLK/SCK); also elsewhere on the board
SD_~CS: J10.2 (DAT3/~CS), R24.2; also elsewhere on the board
USER_BUTTON: R22.2, SW2.2; also elsewhere on the board
VBATT: C29.1, C31.1, J5.3, J9.2 (+), U6.3 (VIN1), U8.3 (V_{BAT}), U9.2 (CELL), U9.3 (VDD)
VDDA: J5.11; also elsewhere on the board
VUSB: C28.1, J5.2, R19.1, U6.6 (VIN2), U8.4 (VIN); also elsewhere on the board
XBLR_IO0: J8.2; also elsewhere on the board
XBLR_IO1: J8.3; also elsewhere on the board
XBLR_IO2: J8.4; also elsewhere on the board
XBLR_IO3: J8.5; also elsewhere on the board
XBLR_IO4: J8.6; also elsewhere on the board
XBLR_IO5: J8.7; also elsewhere on the board
XBLR_IO6: J8.8; also elsewhere on the board
XBLR_IO7: J8.9; also elsewhere on the board
XBLR_IO8: J8.10; also elsewhere on the board
XBLR_IO9: J8.11; also elsewhere on the board
XBLR_IO10: J6.11; also elsewhere on the board
XBLR_IO11: J6.10; also elsewhere on the board
XBLR_IO12: J6.9; also elsewhere on the board
XBLR_IO15: J6.6; also elsewhere on the board
XBLR_IO16: J6.5; also elsewhere on the board
XBLR_IO17: J6.4; also elsewhere on the board
XBLR_IO18: J6.3; also elsewhere on the board
XBLR_IO19: J6.2; also elsewhere on the board
XBLR_RX/IO14: J6.7; also elsewhere on the board
XBLR_TX/IO13: J6.8; also elsewhere on the board
~BOOT: SW4.2, TP2.1; also elsewhere on the board
~ON: J5.5, R15.1, U6.4 (~ON)
~RESET: J5.6, R25.2, SW3.2; also elsewhere on the board

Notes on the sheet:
LEDs
Buttons
Cut LP trace to make uSD card and RGB LED powered off by default
I2C Address: 0x36
Charge current: I_CHG = 1000 / R_PROG R_PROG = 2.2k I_CHG = 455mA
Cut CHG trace to disable charge LED
Peripheral Power
Battery Charger - MCP73831
!!! WARNING !!! Do not drive uSD card pins high if card is not powered, otherwise damage could occur!
Cut I2C traces to disable I2C pullup resistors
uSD Card Connector
IoT Node Headers
Power Input and Voltage Regulator
XBLR Headers
Cut PWR trace to disable power LED
Battery Fuel Gauge - MAX17048
Qwiic Connector

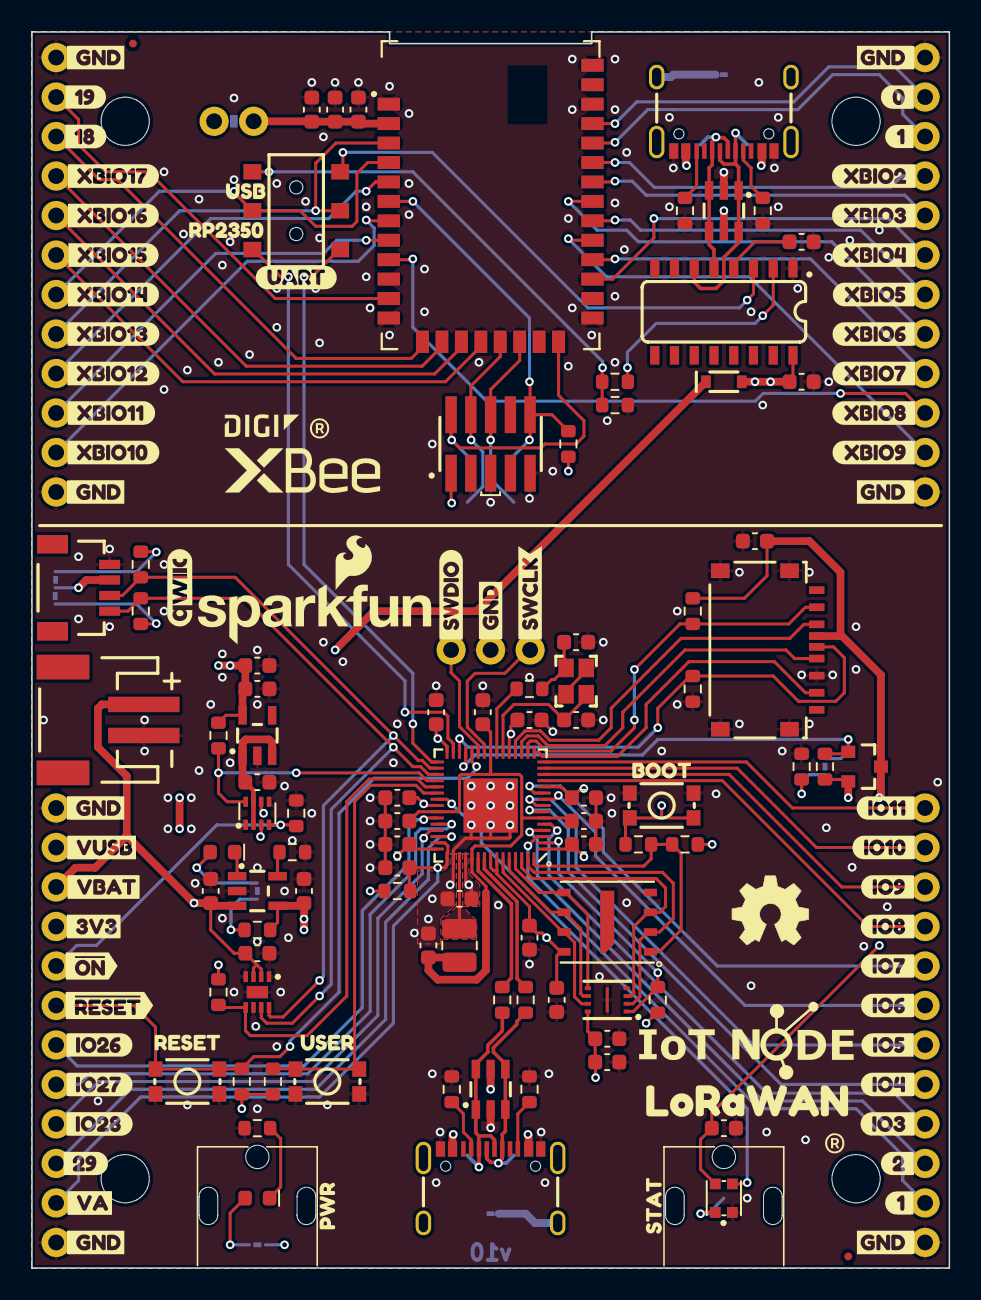
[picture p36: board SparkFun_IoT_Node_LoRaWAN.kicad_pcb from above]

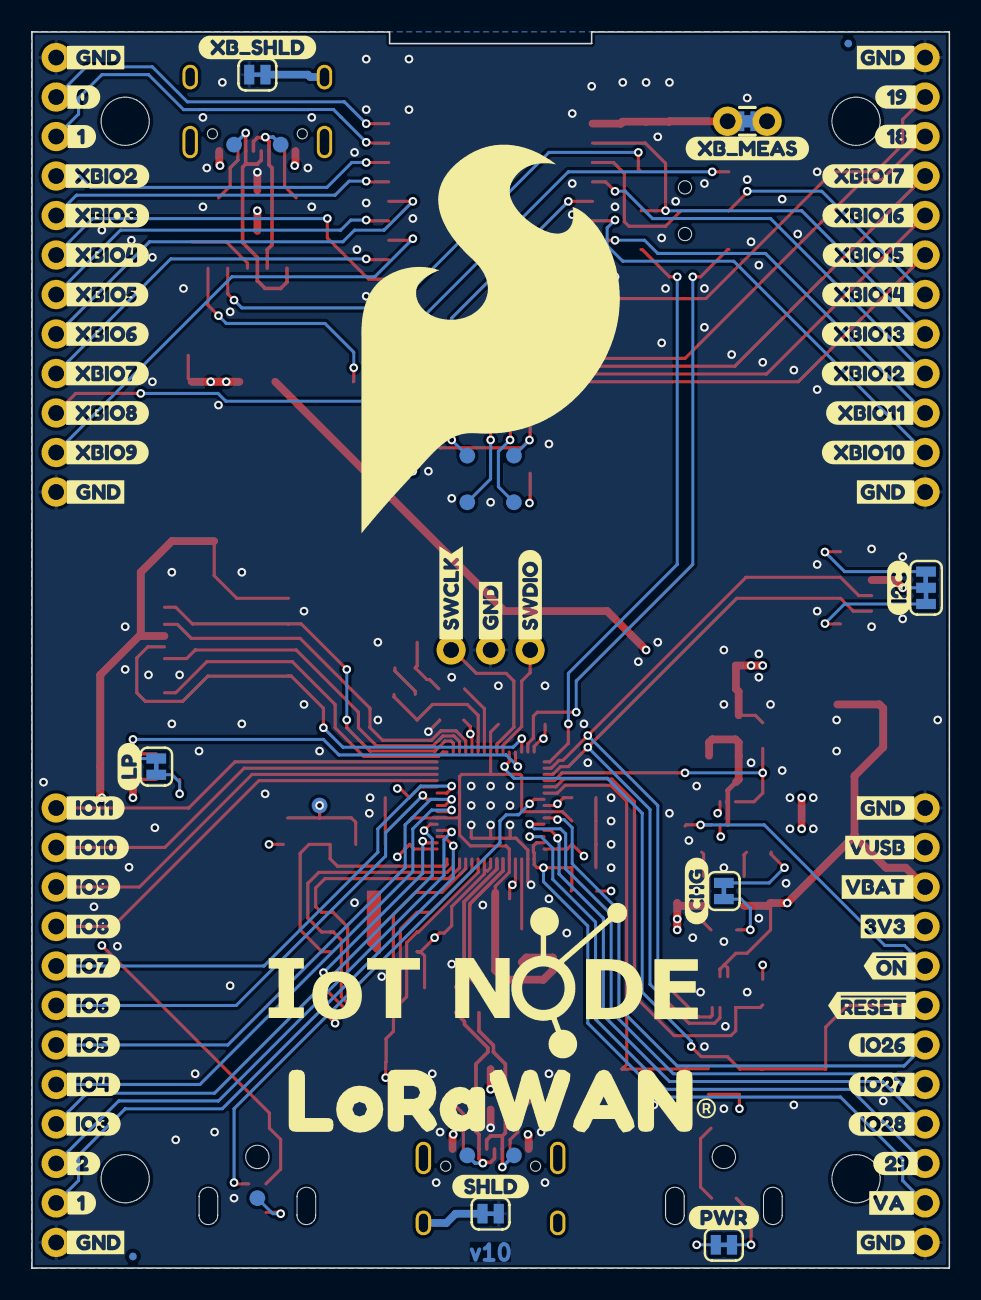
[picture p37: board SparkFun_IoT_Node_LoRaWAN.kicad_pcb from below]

Board: 4 copper layers, 59.0 x 79.5 mm, 238 parts (78 on the bottom side), 105 nets.

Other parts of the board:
Ref**: Val**; OSHW_Logo_5mm
kibuzzard-669A9B0A: G***; kibuzzard-669A9B0A
kibuzzard-669E9F4F: G***; kibuzzard-669E9F4F
kibuzzard-669E9F62: G***; kibuzzard-669E9F62
kibuzzard-669E97BF: G***; kibuzzard-669E97BF
kibuzzard-669E97C2: G***; kibuzzard-669E97C2
kibuzzard-669E97C7: G***; kibuzzard-669E97C7
kibuzzard-669E97CC: G***; kibuzzard-669E97CC
kibuzzard-669E97CF: G***; kibuzzard-669E97CF
kibuzzard-669E97D3: G***; kibuzzard-669E97D3
kibuzzard-669E97D7: G***; kibuzzard-669E97D7
kibuzzard-669E97DA: G***; kibuzzard-669E97DA
kibuzzard-669E976B: G***; kibuzzard-669E976B
kibuzzard-669E977C: G***; kibuzzard-669E977C
kibuzzard-669E977F: G***; kibuzzard-669E977F
kibuzzard-669E978A: G***; kibuzzard-669E978A
kibuzzard-669E978E: G***; kibuzzard-669E978E
kibuzzard-669E979E: G***; kibuzzard-669E979E
kibuzzard-669E9751: G***; kibuzzard-669E9751
kibuzzard-669E9757: G***; kibuzzard-669E9757
kibuzzard-669E9763: G***; kibuzzard-669E9763
kibuzzard-669E9784: G***; kibuzzard-669E9784
kibuzzard-669E9793: G***; kibuzzard-669E9793
kibuzzard-669E9798: G***; kibuzzard-669E9798
kibuzzard-669EA03D: G***; kibuzzard-669EA03D
kibuzzard-669EA04A: G***; kibuzzard-669EA04A
kibuzzard-669EA05B: G***; kibuzzard-669EA05B
kibuzzard-669EA5B0: G***; kibuzzard-669EA5B0
kibuzzard-669EA5C9: G***; kibuzzard-669EA5C9
kibuzzard-669EA5FC: G***; kibuzzard-669EA5FC
kibuzzard-669EA026: G***; kibuzzard-669EA026
kibuzzard-669EA63A: G***; kibuzzard-669EA63A
kibuzzard-669EA63F: G***; kibuzzard-669EA63F
kibuzzard-669EA64A: G***; kibuzzard-669EA64A
kibuzzard-669EA64E: G***; kibuzzard-669EA64E
kibuzzard-669EA604: G***; kibuzzard-669EA604
kibuzzard-669EA643: G***; kibuzzard-669EA643
kibuzzard-669EA654: G***; kibuzzard-669EA654
kibuzzard-669EC8FA: G***; kibuzzard-669EC8FA
kibuzzard-669ED447: G***; kibuzzard-669ED447
kibuzzard-671A9B5A: G***; kibuzzard-671A9B5A
kibuzzard-671A9B9C: G***; kibuzzard-671A9B9C
kibuzzard-671A9B60: G***; kibuzzard-671A9B60
kibuzzard-671A9B96: G***; kibuzzard-671A9B96
kibuzzard-671A9BD9: G***; kibuzzard-671A9BD9
kibuzzard-671A9BE0: G***; kibuzzard-671A9BE0
kibuzzard-671A9C1E: G***; kibuzzard-671A9C1E
kibuzzard-671A9C23: G***; kibuzzard-671A9C23
kibuzzard-671A9C32: G***; kibuzzard-671A9C32
kibuzzard-671A9C38: G***; kibuzzard-671A9C38
kibuzzard-671A9CA4: G***; kibuzzard-671A9CA4
kibuzzard-671A9CA8: G***; kibuzzard-671A9CA8
kibuzzard-6691B3A2, kibuzzard-6691B3A2#2, kibuzzard-6691B3A2#3, kibuzzard-6691B3A2#4, kibuzzard-6691B3A2#5, kibuzzard-6691B3A2#6, kibuzzard-6691B3A2#7: G***; kibuzzard-6691B3A2
kibuzzard-6691B3CB: G***; kibuzzard-6691B3CB
kibuzzard-6691B3E7: G***; kibuzzard-6691B3E7
kibuzzard-6691B3EC: G***; kibuzzard-6691B3EC
kibuzzard-6691B3F1: G***; kibuzzard-6691B3F1
kibuzzard-6691B3F5: G***; kibuzzard-6691B3F5
kibuzzard-6691B3F9: G***; kibuzzard-6691B3F9
kibuzzard-6691B3FD: G***; kibuzzard-6691B3FD
kibuzzard-6691B4CC: G***; kibuzzard-6691B4CC
kibuzzard-6691B5FB: G***; kibuzzard-6691B5FB
kibuzzard-6691B6A1: G***; kibuzzard-6691B6A1
kibuzzard-6691B6A6: G***; kibuzzard-6691B6A6
kibuzzard-6691B6AB: G***; kibuzzard-6691B6AB
kibuzzard-6691B6B0: G***; kibuzzard-6691B6B0
kibuzzard-6691B6B5: G***; kibuzzard-6691B6B5
kibuzzard-6691B6B9: G***; kibuzzard-6691B6B9
kibuzzard-6691B6EC: G***; kibuzzard-6691B6EC
kibuzzard-6691B7AB, kibuzzard-6691B7AB#2: G***; kibuzzard-6691B7AB
kibuzzard-6691B7BF, kibuzzard-6691B7BF#2: G***; kibuzzard-6691B7BF
kibuzzard-6691B8D3: G***; kibuzzard-6691B8D3
kibuzzard-6691B8DD: G***; kibuzzard-6691B8DD
kibuzzard-6691B43C: G***; kibuzzard-6691B43C
kibuzzard-6691B44C: G***; kibuzzard-6691B44C
kibuzzard-6691B48E: G***; kibuzzard-6691B48E
kibuzzard-6691B60A: G***; kibuzzard-6691B60A
kibuzzard-6691B62B: G***; kibuzzard-6691B62B
kibuzzard-6691B62F: G***; kibuzzard-6691B62F
kibuzzard-6691B72F: G***; kibuzzard-6691B72F
kibuzzard-6691B73B: G***; kibuzzard-6691B73B
kibuzzard-6691B276, kibuzzard-6691B276#2, kibuzzard-6691B276#3, kibuzzard-6691B276#4, kibuzzard-6691B276#5, kibuzzard-6691B276#6, kibuzzard-6691B276#7, kibuzzard-6691B276#8, kibuzzard-6691B276#9: G***; kibuzzard-6691B276
kibuzzard-6691B296: G***; kibuzzard-6691B296
kibuzzard-6691B419: G***; kibuzzard-6691B419
kibuzzard-6691B440: G***; kibuzzard-6691B440
kibuzzard-6691B444: G***; kibuzzard-6691B444
kibuzzard-6691B448: G***; kibuzzard-6691B448
kibuzzard-6691B450: G***; kibuzzard-6691B450
kibuzzard-6691B472: G***; kibuzzard-6691B472
kibuzzard-6691B623: G***; kibuzzard-6691B623
kibuzzard-6691B627: G***; kibuzzard-6691B627
kibuzzard-6691B633: G***; kibuzzard-6691B633
kibuzzard-6691B637: G***; kibuzzard-6691B637
kibuzzard-6691B649: G***; kibuzzard-6691B649
kibuzzard-6691B661: G***; kibuzzard-6691B661
kibuzzard-6691B670: G***; kibuzzard-6691B670
kibuzzard-6691B712: G***; kibuzzard-6691B712
kibuzzard-6691B750: G***; kibuzzard-6691B750
kibuzzard-6691B763: G***; kibuzzard-6691B763
kibuzzard-6691B872: G***; kibuzzard-6691B872
kibuzzard-6691B926: G***; kibuzzard-6691B926
kibuzzard-6691B931: G***; kibuzzard-6691B931
kibuzzard-6691B952: G***; kibuzzard-6691B952
kibuzzard-66999523: G***; kibuzzard-66999523

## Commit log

2024-07-02 Add initial design
    Create symbol and footprint for XBLR
    Majority of schematic components, still missing headers and need to determine pinouts
    Initial board dimensions set, components placed but not arranged, and nothing routed
    [SparkFun_IoT_Node_LoRaWAN.kicad_pcb, SparkFun_IoT_Node_LoRaWAN.kicad_sch]
2024-07-03 v01 schematic updates
    Add remaining schematic components
    Split schematic into multiple sheets
    Still need to define pinouts for RP2350, XBLR, and headers
    [SparkFun_IoT_Node_LoRaWAN.kicad_pcb, SparkFun_IoT_Node_LoRaWAN.kicad_sch, power_peripherals.kicad_sch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]
2024-07-08 Initial board layout
    Board outline determined based off selected enclosure
    Clusters of components placed and routed
    Waiting for feedback before finishing routing
    [SparkFun_IoT_Node_LoRaWAN.kicad_pcb, SparkFun_IoT_Node_LoRaWAN.kicad_sch, power_peripherals.kicad_sch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]
2024-07-11 Review updates
    Remove region selection resistors
    Add uSD card connector
    Move XBLR USB connector within enclosure
    [SparkFun_IoT_Node_LoRaWAN.kicad_pcb, power_peripherals.kicad_sch, rp2350.kicad_sch]
2024-07-12 Finish connections and routing
    [SparkFun_IoT_Node_LoRaWAN.kicad_pcb, power_peripherals.kicad_sch, rp2350.kicad_sch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]
2024-07-12 Add silk labels to UART switch
    [SparkFun_IoT_Node_LoRaWAN.kicad_pcb]
2024-07-12 Add level shifter to CH340 TX pin
    [SparkFun_IoT_Node_LoRaWAN.kicad_pcb, xblr.kicad_sch]
2024-07-15 Improve GND stitching
    Add lots of GND vias
    Nudge tracks to connect GND pour regions
    [SparkFun_IoT_Node_LoRaWAN.kicad_pcb]
2024-07-15 Clean up schematic
    Add lines between regions
    Add instruction text to all jumpers
    [power_peripherals.kicad_sch, rp2350.kicad_sch, xblr.kicad_sch]
2024-07-18 Update project libraries
    Add RP2350
    Update XBLR to KiCad standards
2024-07-18 v02 Schematic Updates
    Bump version number to v02
    Fix RP2350, APS6404L, and 12MHz crystal to use proper KiCad symbols and footprints instead of imported from Eagle
    Change schematic to use 2x Ledger sheets
    Change Qwiic connector to power from 3.3V
    Change user button and RGB LED to small mount versions
    Split headers into XBLR and IoT Node specific regions
    [SparkFun_IoT_Node_LoRaWAN.kicad_sch, power_peripherals.kicad_sch, rp2350.kicad_sch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]
2024-07-18 v02 Board Updates
    Still in progress...
    Update RP2350, APS6404L, and 12MHz crystal footprints
    Move USB-C connector to be centered, and not go through wall of enclosure
    Move power LED and RGB LED to be symmetric along south edge of board
    Move battery connector, Qwiic connector, and uSD card connector to middle edges of board
    Move IoT Node headers south
    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
    [SparkFun_IoT_Node_LoRaWAN.kicad_pcb]
2024-07-22 Finish v02 updates
    Clean up schematic
    Add test points for boot button and RGB LED output
    Update pinouts of headers and RP2350
    Fix pad shape of XBLR footprint
    Finish routing
    Update logos
    Update jumper names
    Add measures
    [SparkFun_IoT_Node_LoRaWAN.kicad_pcb, SparkFun_IoT_Node_LoRaWAN.kicad_sch, power_peripherals.kicad_sch]
2024-07-22 Add chungus SparkFun flame to back silkcreen
    [SparkFun_IoT_Node_LoRaWAN.kicad_pcb]
2024-07-24 Re-annotate schematic
    [SparkFun_IoT_Node_LoRaWAN.kicad_pcb, SparkFun_IoT_Node_LoRaWAN.kicad_sch, power_peripherals.kicad_sch]
2024-07-24 Design review updates
    Fix typo in USB calculations
    Space out buttons in schematic
    Add courtyard to flash memory
    Reposition measures outside of enclosure outline
    Reposition LEd silk outside of light pipe footprint
    [SparkFun_IoT_Node_LoRaWAN.kicad_pcb, SparkFun_IoT_Node_LoRaWAN.kicad_sch, power_peripherals.kicad_sch]
2024-07-24 Design review updates
    Move text for D1 and D3 to not overlap wire
    Add regulator max output current
    Add battery charge current
    Add (R) to LoRaWAN silkscreen
    Name copper zones
    Nudge mesaure text on let side to not overlap lines
    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
    [SparkFun_IoT_Node_LoRaWAN.kicad_pcb, SparkFun_IoT_Node_LoRaWAN.kicad_sch, power_peripherals.kicad_sch]
2024-07-24 Update board stackup
    [SparkFun_IoT_Node_LoRaWAN.kicad_pcb]
2024-07-24 Make jumper reference designators visible
    [SparkFun_IoT_Node_LoRaWAN.kicad_sch, power_peripherals.kicad_sch]
2024-07-24 Cosmetic tweaks
    Nudge IO 29 silk away from mounting hole
    Add VDDA RC filter cutoff frequency
    [SparkFun_IoT_Node_LoRaWAN.kicad_pcb, SparkFun_IoT_Node_LoRaWAN.kicad_sch]
2024-07-24 Move STAT silk
    [SparkFun_IoT_Node_LoRaWAN.kicad_pcb]
2024-07-24 Spread out reset and user buttons
    [SparkFun_IoT_Node_LoRaWAN.kicad_pcb]
2024-07-24 Add soldermask cutout for CBI footprints
    [SparkFun_IoT_Node_LoRaWAN.kicad_pcb]
2024-07-24 Add v02 production files
    [SparkFun_IoT_Node_LoRaWAN.GBL, SparkFun_IoT_Node_LoRaWAN.GBO, SparkFun_IoT_Node_LoRaWAN.GBS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]
2024-10-23 Update dimensions of box
    Accidentally used the top dimensions instead of bottom dimensions. Board needs to shrink.
    [SparkFun_IoT_Node_LoRaWAN.kicad_pcb]
2024-10-24 Shrink board to fit new enclosure dimensions
    [SparkFun_IoT_Node_LoRaWAN.kicad_pcb, SparkFun_IoT_Node_LoRaWAN.kicad_sch, power_peripherals.kicad_sch]
2024-10-24 Symbol and footprint update
    [SparkFun_IoT_Node_LoRaWAN.kicad_pcb, SparkFun_IoT_Node_LoRaWAN.kicad_sch, power_peripherals.kicad_sch]
2024-10-24 Bump version number to v10
    [SparkFun_IoT_Node_LoRaWAN.kicad_pcb, SparkFun_IoT_Node_LoRaWAN.kicad_sch, power_peripherals.kicad_sch]
2024-10-24 Fix IoT Node Logo
    Lines were poking into the O of Node for some reason. "Stroke to path" in InkScape fixed it.
    Also add SVG of logo
    [SparkFun_IoT_Node_LoRaWAN.kicad_pcb]
2024-10-24 Fix dimension of debug header
    [SparkFun_IoT_Node_LoRaWAN.kicad_pcb]
2024-10-24 Fix dimensions of board
    [SparkFun_IoT_Node_LoRaWAN.kicad_pcb]
2024-10-29 Design review updates
    Fix layers to standard SFE usage
    Add link to enclosure and PDF of dimensions
    Move fiducials away from PTH pads
    Add USB test points
    Add XBLR debug test points
    [SparkFun_IoT_Node_LoRaWAN.kicad_pcb, SparkFun_IoT_Node_LoRaWAN.kicad_sch]
2024-10-30 Add XBLR 3D model
    Also fix RP2350A library reference
    [SparkFun_IoT_Node_LoRaWAN.kicad_pcb, SparkFun_IoT_Node_LoRaWAN.kicad_sch, XBLR_UFL.step]
2024-10-30 Set XBLR debug header to DNP
    [SparkFun_IoT_Node_LoRaWAN.kicad_pcb, SparkFun_IoT_Node_LoRaWAN.kicad_sch]
2024-10-30 Add OSHW logo to silkscreen
    [SparkFun_IoT_Node_LoRaWAN.kicad_pcb]
2024-11-04 Add v10 production files
    [SparkFun_IoT_Node_LoRaWAN.GBL, SparkFun_IoT_Node_LoRaWAN.GBO, SparkFun_IoT_Node_LoRaWAN.GBS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]
2024-11-04 Checklist update
    Update 1.4A inductor
    Update date design
    Add I2C address of fuel gauge
    [SparkFun_IoT_Node_LoRaWAN.kicad_pcb, SparkFun_IoT_Node_LoRaWAN.kicad_sch, power_peripherals.kicad_sch]
2024-11-18 Library update
    [SparkFun_IoT_Node_LoRaWAN.kicad_pcb, power_peripherals.kicad_sch]
2024-12-02 Set SWD header as DNP in board file
    [SparkFun_IoT_Node_LoRaWAN.kicad_pcb]
2025-01-06 Fix print orientation
2025-05-02 Update quick_start.md
    Adding recommendation for using phone camera for scanning data matrix on XBee.
2025-05-02 Update quick_start.md
    Removing button formatting to fix rendering.
2025-05-02 Update quick_start.md
    Attempt #2 to fix button rendering.
2025-05-02 Update quick_start.md
    Removing login button since it's not rendering properly.

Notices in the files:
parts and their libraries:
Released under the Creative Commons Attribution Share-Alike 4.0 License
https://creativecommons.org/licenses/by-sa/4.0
